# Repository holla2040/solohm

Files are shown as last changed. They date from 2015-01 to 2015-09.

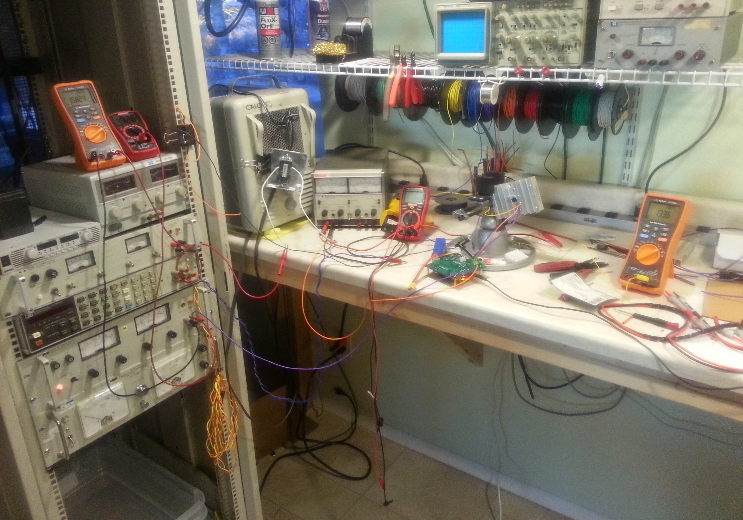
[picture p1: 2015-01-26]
electronicLoadCC3200/board/testing/150125-171110 - Setup.jpg

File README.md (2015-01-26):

solohm
======

Open Source Solar Panel Electronic Load

This project is a hardware/firmware design to aid in testing of solar panels. solohm is powered from the panel's output and an off-the-shelf lipo battery, it can load the panel at its maximum power point, WiFi UDP broadcast current and voltage readings packets, perform IV curve sweeps and measure many temperatures at different panel locations. 

SolOhm replaces bulky expensive, AC-powered, non-waterproof, non-high-temperature rated, multi-unit, wired-communication test equipment with a single unit that's inexpensive, panel-powered, waterproof, industrial temperature rated, and wireless. The goal is 5 minute install: bolt SolOhm to your frame, connect your panel's + and - connectors, attach temperature probes and start testing.  

Specifications
<ul>
<li>Input voltage - 50VDC maximum</li>
<li>Input current - 10A maximum, fused</li>
<li>Input power - 300W maximum</li>
<li>Operating temperature - &lt; 130F, acquisition electronics TEC cooled</li>
<li>Display - OLED graphic display</li>
<li>User interface - IR remote DirectTV RC65X or Sony TV</li> 
<li>MPPT tracking - periodic sweep, perturb/observe, manual</li>
<li>Mechanical - frame/poll attachment, IP63, extruded aluminium, glass/plexiglass, passive heatsink</li>
<li>IV sweep time - &lt; 1 sec, VOC to ISC, 500 samples, Vpanel@ISC < 0.25V@8A<li>
<li>ADC resolution - 12 bit, 4096 steps full scale</li>
<li>Temperature probes - DS18B20, COTS stainless steel, multi-drop, +/-0.5C over -10C to +85C</li>
<li>Power supply - COTS 3S LIPO battery, panel powered charger, 24 hour operation</li>
<li>Data transmission - UDP broadcast and control, HTTP REST</li>
<li>Data collection - micro SD slot</li>
<li>Timestamp - UTC via NTP source with battery-backed real time clock</li>
<li>Firmware - OTA updates (planned)</li>
<li>Calibration - Requires 40V@10A power supply, precision voltmeter and ammeter</li>

</ul>

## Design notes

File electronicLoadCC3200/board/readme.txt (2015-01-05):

This information, board files, assembly instructions and bill of
materials is company confidental.
Not for distribution.

board
    solohm

version
    0.1
    150101

description
    Top layer:                  pcbname.GTL
    Bottom layer:               pcbname.GBL
    Solder Stop Mask top:       pcbname.GTS
    Solder Stop Mask Bottom:    pcbname.GBS
    Silk Top:                   pcbname.GTO
    Silk Bottom:                pcbname.GBO
    NC Drill:                   pcbname.TXT

    drd drill data
    dri drill info
    gpi gerber info

fudicials at
    0.25,0.1
    3.6,3.8

layer stack up sequence
    top     x.GTL
    bottom  x.GBL

contact info
    Craig Hollabaugh
    970 690 4911
    craig@hollabaugh.com

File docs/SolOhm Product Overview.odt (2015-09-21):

SolOhm

Lowering Panel Testing Costs

Montrose, Colorado

Craig Hollabaugh

holla@solohm.com

970 316 3165

https://github.com/holla2040/solohm

SolOhm - Monitor

Lowering Panel Testing Costs

SolOhm - Monitor

Ammeter, 10A range, 1.2mOhm sense resistor

Voltmeter, 50VDC range

Temperature Sensors, multiple, daisy-chained, digital +/- 0.5C -10 to +85C, DS18B20

Wireless Status Broadcast, WiFi

Calibration, requires external power supply, ammeter and voltmeter

Panel Powered

Plastic Enclosure, 3”x3”x2”, IP54

String inverter or micro-inverter operation

HTTP REST and UDP broadcast communications

Open Source hardware and software

Over the air firmware update

Arduino development environment, experienced firmware developer not required

SolOhm - Sweep

Lowering Panel Testing Costs

SolOhm - Sweep

Ammeter, 10A range, 1.2mOhm sense resistor

Voltmeter, 50VDC range

Temperature Sensors, multiple, daisy-chained, digital +/- 0.5C -10 to +85C, DS18B20

Wireless Status Broadcast, WiFi

Calibration, requires external power supply, ammeter and voltmeter

Panel Powered

Plastic Enclosure, 3”x3”x3”, IP54

String inverter or micro-inverter operation

HTTP REST and UDP broadcast communications

Open Source hardware and software

Over the air firmware update

Arduino development environment, experienced firmware developer not required

IV Curve Sweep, 300W range, less than 1 second acquisition time

Internal string disconnect circuit

24-hour operation using LiPo battery

SolOhm - Load

Lowering Panel Testing Costs

SolOhm - Load

Ammeter, 10A range, 1.2mOhm sense resistor

Voltmeter, 50VDC range

Temperature Sensors, multiple, daisy-chained, digital +/- 0.5C -10 to +85C, DS18B20

Wireless Status Broadcast, WiFi

Calibration, requires external power supply, ammeter and voltmeter

Panel Powered

Enclosure, 8”x8”x5”, IP54

String inverter or micro-inverter operation

HTTP REST and UDP broadcast communications

Open Source hardware and software

Over the air firmware update

Arduino development environment, experienced firmware developer not required

IV Curve Sweep, 300W range, less than 1 second acquisition time

Internal string disconnect circuit

24-hour operation using LiPo battery

MPPT

Fan-cooled heat sink

TEC cooled analog circuitry

MPPT, CV, CC modes

Real time clock for timestamp generation

uSD card for disconnected data logging

OLED Display

GSM/GPRS option

SolOhm - µInverter

Lowering Panel Testing Costs

SolOhm - µInverter

Ammeter, 10A range, 1.2mOhm sense resistor

Voltmeter, 50VDC range

Temperature Sensors, multiple, daisy-chained, digital +/- 0.5C -10 to +85C, DS18B20

Wireless Status Broadcast, WiFi

Calibration, requires external power supply, ammeter and voltmeter

Panel Powered

Enclosure, 8”x8”x5”, IP54

HTTP REST and UDP broadcast communications

Open Source hardware and software

Over the air firmware update

Arduino development environment, experienced firmware developer not required

IV Curve Sweep, 300W range, less than 1 second acquisition time

24-hour operation using LiPo battery

MPPT

Fan-cooled heat sink

TEC cooled analog circuitry

MPPT, CV, CC modes

Real time clock for timestamp generation

uSD card for disconnected data logging

OLED Display

GSM/GPRS option

Grid tie

High-precision multiple PWM/ADC control loops

Precision AC measurements, line frequency, voltage, current

On-board DSP

SolOhm Product Overview - 150205

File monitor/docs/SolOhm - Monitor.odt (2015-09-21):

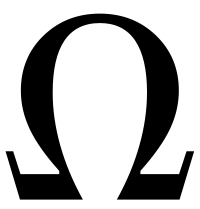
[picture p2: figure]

SolOhm – Monitor 7/1/2015

High-Precision Panel/String Monitor

Feature Set

Use Cases Supported | ● Single panel power verification with temperatures ● Microinverter MPPT verification and sweep capture ● String power verification with temperatures ● String inverter MPPT verification and sweep capture ● Electronic load sweep capture
Tri-range Voltmeter LTC2348-18 | Full scale Resolution 60VDC < 1mV 120VDC < 2mV 700VDC < 10mV
Ammeter LTC2348-18 | 10A < 0.2mA
Temperature Sensor Inputs LTC2983 | 5 RTD – 2,3,4 wire 10 Thermocouples - B, E, J, K, N, S, R, T 0.1°C accuracy and 0.001°C resolution
Operating Temperature Range | -20°C to 60°C, holds measurement accuracy over range
Real Time Clock | NTP time reference synchronization Disconnected accuracy < 0.3sec/day
Power Supply Turnigy Lipo | Rechargeable/replaceable COTS 3-cell LiPo battery Parasitically panel powered, < 0.01% consumption Consumption disabled during data acquisition
Sampling | Simultaneous voltage and current measurement No multi-channel multiplexer 18-bit, 200K samples/sec max, full differential Configurable sample rate between 1/5min – 200K/sec
Data Storage uSDHC | 4GB non-removable – FAT32 file system, timestamped data, date-based filenames, CSV format
Configuration | Bluetooth enabled cell phone application (IOS/Android) Settings: user label, sample rate, data transfer frequency/destination URL, filename format, WiFi configuration, timezone, calibration constants
Communication | Bluetooth Low Energy configuration and data display, phone app will show live summary table of all field devices, WiFi data transfer
Calibration | Requires power supply and precision voltmeter/ammeter
Enclosure | 3”x5”x3”, plastic, IP65, MC4 pigtail connections, mountable, no high voltage access, no buttons, no display, safety markings, viewable serial number
Price | $990.00

SolOhm Monitor v1.0 ● SolOhm ● Montrose, CO, USA ● 970 316 3165 ● www.solohm.com

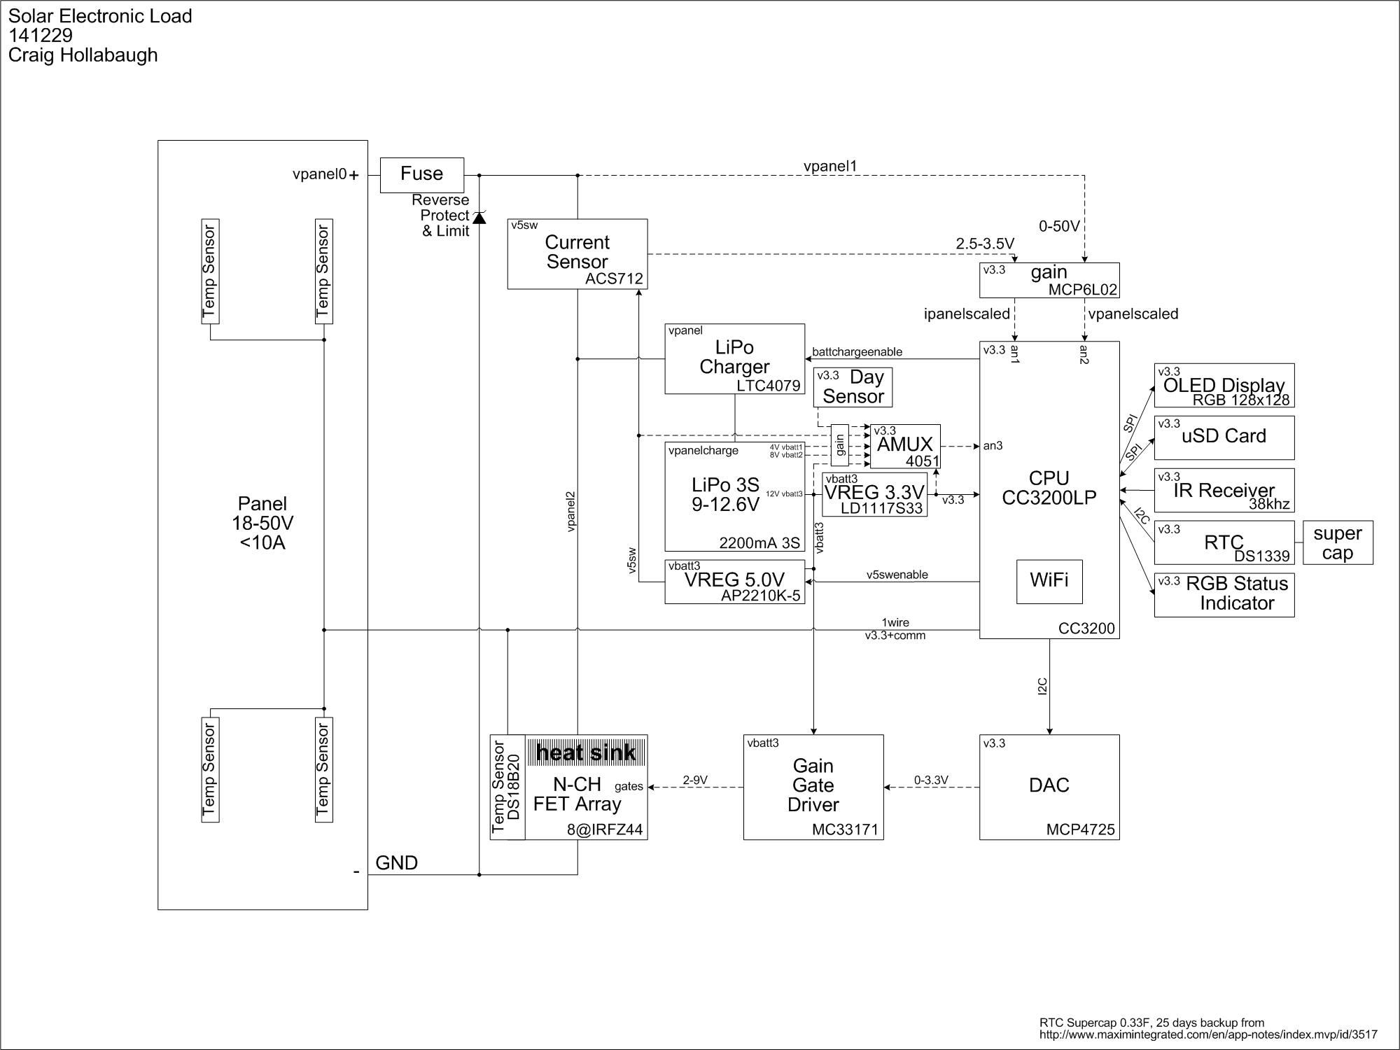
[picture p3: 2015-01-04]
electronicLoadCC3200/design/Solar Electronic Load LiPo Architecture.jpg

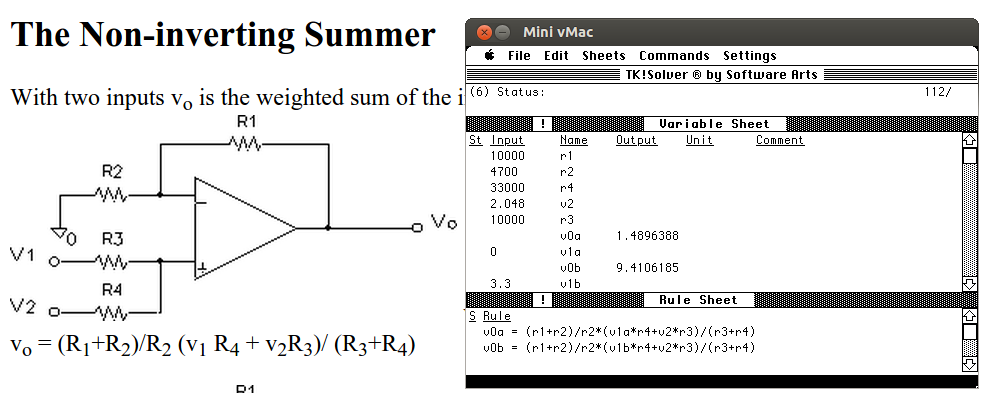
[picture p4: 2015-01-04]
electronicLoadCC3200/design/gate driver biasing.png

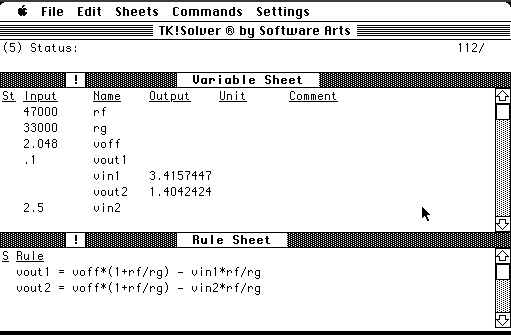
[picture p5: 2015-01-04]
electronicLoadCC3200/design/current gain with offset.png

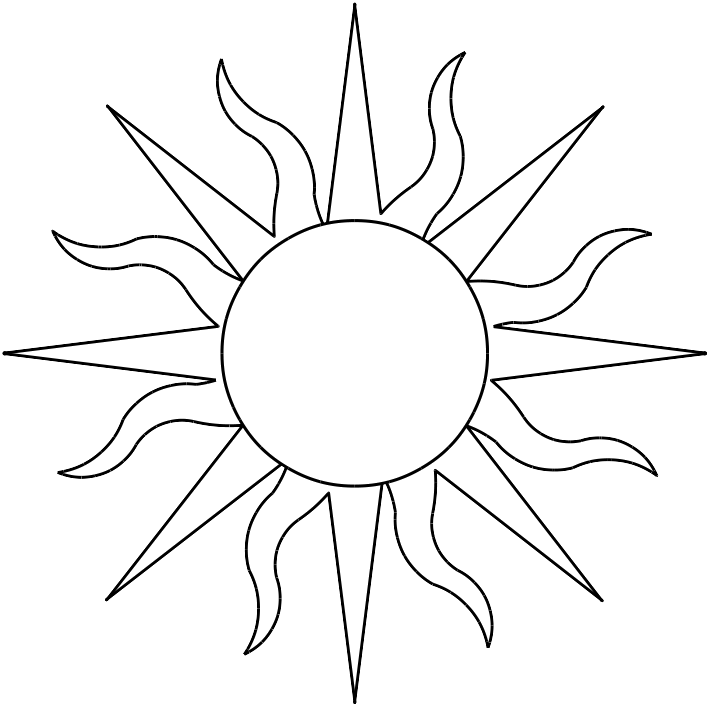
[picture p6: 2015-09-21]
docs/sol.png

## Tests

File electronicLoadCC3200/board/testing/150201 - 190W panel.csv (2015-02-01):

dac | voltage | current | rload | power
1000 | 40.40 | 0.04 | 935.04 | 1.74
1004 | 40.37 | 0.05 | 757.05 | 2.15
1008 | 40.39 | 0.04 | 992.93 | 1.64
1012 | 40.35 | 0.04 | 933.91 | 1.74
1016 | 40.36 | 0.04 | 836.20 | 1.94
1020 | 40.37 | 0.05 | 757.05 | 2.15
1024 | 40.31 | 0.04 | 881.42 | 1.84
1028 | 40.32 | 0.04 | 881.68 | 1.84
1032 | 40.42 | 0.04 | 993.83 | 1.64
1036 | 40.40 | 0.04 | 883.29 | 1.84
1040 | 40.36 | 0.04 | 836.20 | 1.94
1044 | 40.39 | 0.05 | 757.28 | 2.15
1048 | 40.39 | 0.05 | 757.28 | 2.15
1052 | 40.37 | 0.04 | 992.63 | 1.64
1056 | 40.39 | 0.05 | 795.02 | 2.05
1060 | 40.37 | 0.04 | 882.75 | 1.84
1064 | 40.39 | 0.04 | 992.93 | 1.64
1068 | 40.37 | 0.04 | 882.75 | 1.84
1072 | 40.39 | 0.04 | 883.02 | 1.84
1076 | 40.34 | 0.04 | 991.73 | 1.64
1080 | 40.36 | 0.04 | 882.49 | 1.84
1084 | 40.41 | 0.03 | 1059.47 | 1.54
1088 | 40.39 | 0.04 | 934.75 | 1.74
1092 | 40.40 | 0.04 | 883.29 | 1.84
1096 | 40.36 | 0.05 | 756.82 | 2.15
1100 | 40.37 | 0.04 | 882.75 | 1.84
1104 | 40.39 | 0.04 | 992.93 | 1.64
1108 | 40.40 | 0.04 | 993.23 | 1.64
1112 | 40.36 | 0.04 | 934.19 | 1.74
1116 | 40.39 | 0.04 | 883.02 | 1.84
1120 | 40.39 | 0.04 | 934.75 | 1.74
1124 | 40.39 | 0.04 | 934.75 | 1.74
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

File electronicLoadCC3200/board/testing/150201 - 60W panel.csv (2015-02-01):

dac | voltage | current | rload | power
1000 | 20.50 | 0.06 | 299.17 | 1.40
1002 | 20.52 | 0.06 | 323.42 | 1.30
1004 | 20.50 | 0.05 | 366.95 | 1.14
1006 | 20.50 | 0.07 | 278.58 | 1.50
1008 | 20.53 | 0.06 | 311.20 | 1.35
1010 | 20.50 | 0.06 | 310.64 | 1.35
1012 | 20.52 | 0.05 | 404.00 | 1.04
1014 | 20.56 | 0.05 | 368.05 | 1.14
1016 | 20.51 | 0.06 | 310.83 | 1.35
1018 | 20.51 | 0.05 | 351.25 | 1.19
1020 | 20.53 | 0.05 | 385.06 | 1.09
1022 | 20.53 | 0.07 | 289.03 | 1.45
1024 | 20.52 | 0.05 | 351.46 | 1.19
1026 | 20.55 | 0.05 | 351.88 | 1.20
1028 | 20.52 | 0.06 | 323.42 | 1.30
1030 | 20.50 | 0.06 | 336.46 | 1.24
1032 | 20.51 | 0.06 | 336.66 | 1.24
1034 | 20.53 | 0.06 | 323.61 | 1.30
1036 | 20.53 | 0.06 | 337.06 | 1.25
1038 | 20.53 | 0.06 | 337.06 | 1.25
1040 | 20.53 | 0.05 | 351.67 | 1.19
1042 | 20.55 | 0.05 | 367.83 | 1.14
1044 | 20.53 | 0.06 | 337.06 | 1.25
1046 | 20.51 | 0.05 | 384.60 | 1.09
1048 | 20.51 | 0.05 | 351.25 | 1.19
1050 | 20.52 | 0.06 | 336.86 | 1.25
1052 | 20.51 | 0.05 | 351.25 | 1.19
1054 | 20.52 | 0.05 | 384.83 | 1.09
1056 | 20.53 | 0.06 | 337.06 | 1.25
1058 | 20.55 | 0.05 | 385.29 | 1.09
1060 | 20.55 | 0.06 | 323.81 | 1.30
1062 | 20.52 | 0.06 | 336.86 | 1.25
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

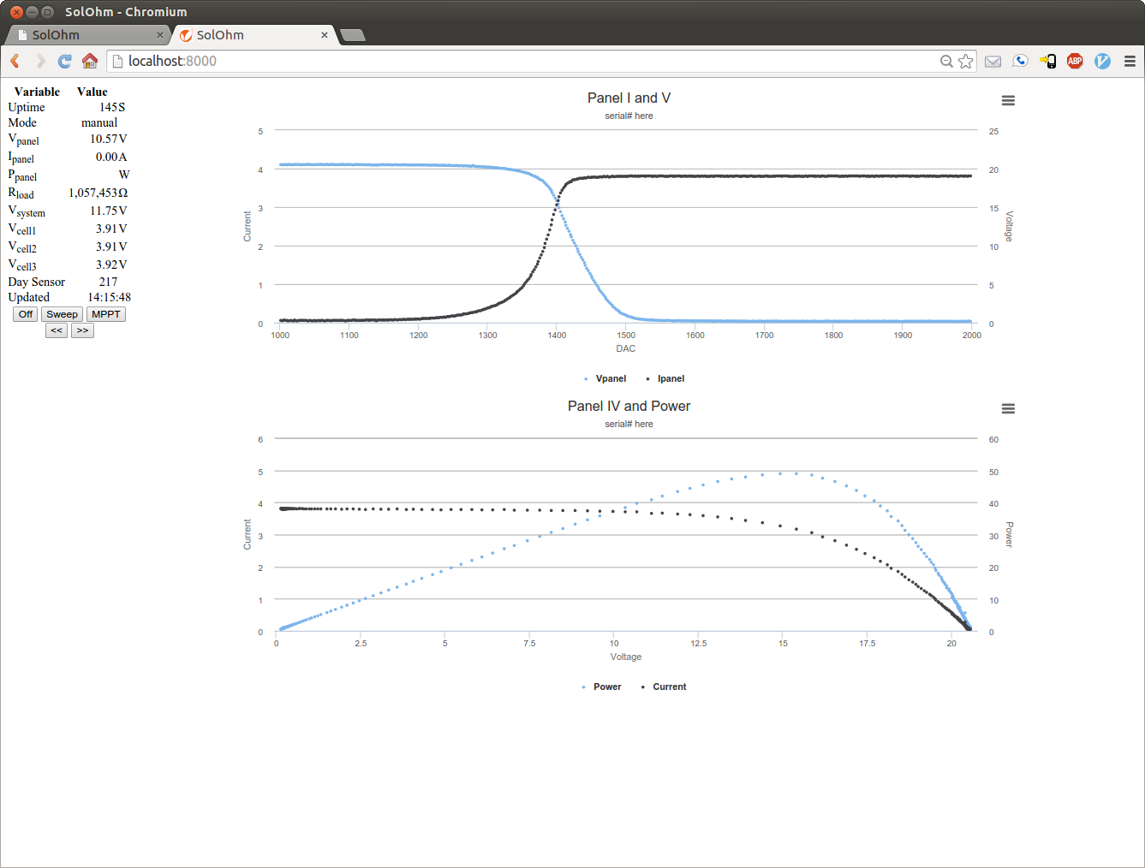
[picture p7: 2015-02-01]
electronicLoadCC3200/board/testing/150201 - 60W panel SolOhm Dashboard.png

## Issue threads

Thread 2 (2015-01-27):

D1 has wrong footprint

holla2040, 2015-01-27:

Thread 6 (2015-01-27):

LED indicators

holla2040, 2015-01-27:
consider ditching activity LED if LP LED is sufficient
    make it RED to match or not drill led holes

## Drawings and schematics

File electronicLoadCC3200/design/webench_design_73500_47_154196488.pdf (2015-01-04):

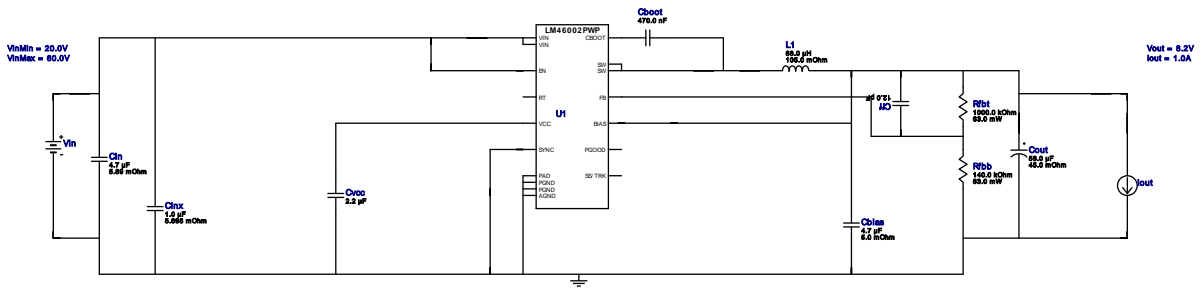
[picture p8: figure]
Cboot 470.0 nF; Cin 4.7 µF 5.89 mOhm; Cinx 1.0 µF 5.698 mOhm; Cout 56.0 µF; 45.0 mOhm; Cvcc 2.2 µF; L1 68.0 µH 105.0 mOhm; Rfbb 140.0 kOhm 63.0 mW; Rfbt 1000.0 kOhm; LM46002PWP; CBOOT; BIAS; SYNC; VIN VIN; VCC; PGOOD; SS/ TRK; AGND; PGND; PAD; VinMin = 20.0V VinMax = 60.0V; Vout = 8.2V Iout = 1.0A; Cbias 4.7 µF 5.0 mOhm; Vin; Iout

Copyright © 2014, Texas Instruments Incorporated | 1 | ti.com/webench

WEBENCH®
Design Report LM46002PWPR : solarelectronicload-lipo December 22, 2014 11:17:29 GMT-08:00

## WEBENCH ® Design Report

Design : 73500/47 LM46002PWPR
solarelectronicload-lipo

VinMin = 20.0V
VinMax = 60.0V
Vout = 8.2V
Iout = 1.0A

Device = LM46002PWPR
Topology = Buck
Created = 12/22/14 11:13:52 AM BOM Cost = $3.80
Footprint = 420.0 mm²
BOM Count = 11
Total Pd = 0.89W
1. The input capacitor included in the BOM only contains a small filter capacitor that should be placed near the IC. Depending on where the power supply is laid out in the system additional bulk capacitance may need to be added to filter the line ripple.
2. If there is no VinTyp specified, WEBENCH will use the VinMax value. To change the VinTyp value, click on the "Change Design Inputs" button under the Optimization Tuning knob. In some applications, while the design requires the input voltage to be a wide range, for a majority of the time, it is operating at a much lower voltage than the maximum input voltage. Sizing the inductor based on the maximum input voltage may yield an inductance much larger than typically needed, causing a larger footprint for the overall design. At the same time, components such as the input capacitor must be rated based on the maximum input voltage. WEBENCH now supports the use of this additional input voltage specification.

## Electrical BOM

# Name | Manufacturer | Part Number | Properties | Qty Price | Footprint

1. Cbias | MuRata | GRM21BR61C475KA88L (http://search.murata.co.jp/Ceramy/PnsearchViewAction.do) Series= X5R | Cap= 4.7 uF ESR= 5.0 mOhm VDC= 16.0 V IRMS= 0.0 A
1 | $0.04
| | | | | 0805 7 mm²
2. Cboot | MuRata | GRM21BR72A474KA73L (http://search.murata.co.jp/Ceramy/PnsearchViewAction.do) Series= X7R

Cap= 470.0 nF
VDC= 100.0 V
IRMS= 0.0 A

1 $0.13
0805 7 mm²
3. Cff | AVX | 06033A120FAT2A (http://www.avx.com/docs/Catalogs/ccog.pdf) Series= C0G/NP0

Cap= 12.0 pF
VDC= 25.0 V
IRMS= 0.0 A

1 $0.10
0603 5 mm²
4. Cin | TDK | C3225X7S2A475M200AB (http://product.tdk.com/capacitor/mlcc/en/documents/mlcc%5Fcommercial%5Fmidvoltage%5Fen.pdf) Series= X7R

Cap= 4.7 uF
ESR= 5.89 mOhm
VDC= 100.0 V
IRMS= 6.7739 A

1 $0.42

1210 15 mm²

5. Cinx | TDK | C3216JB2A105K (http://www.tdk.co.jp/tefe02/e3941%5Fc.pdf) Series= 285

Cap= 1.0 uF
ESR= 5.698 mOhm
VDC= 100.0 V
IRMS= 0.0 A

1 $0.11
1206 11 mm²
6. Cout | Panasonic | 16SVP56M (http://www.edc.sanyo.com/english/pdf/oscon/E32.pdf) Series= 261

Cap= 56.0 uF
ESR= 45.0 mOhm
VDC= 16.0 V
IRMS= 1.89 A

1 $0.49

SM_RADIAL_8MM 113 mm²
7. Cvcc | Kemet | C0603C225K9PACTU (http://www.kemet.com/kemet/web/homepage/kechome.nsf/vapubfiles/F3102%5FY5V.pdf/%24file/F3102%5FY5V.pdf) Series= X5R | Cap= 2.2 uF VDC= 6.3 V IRMS= 0.0 A
1 | $0.02
0603 5 mm²
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

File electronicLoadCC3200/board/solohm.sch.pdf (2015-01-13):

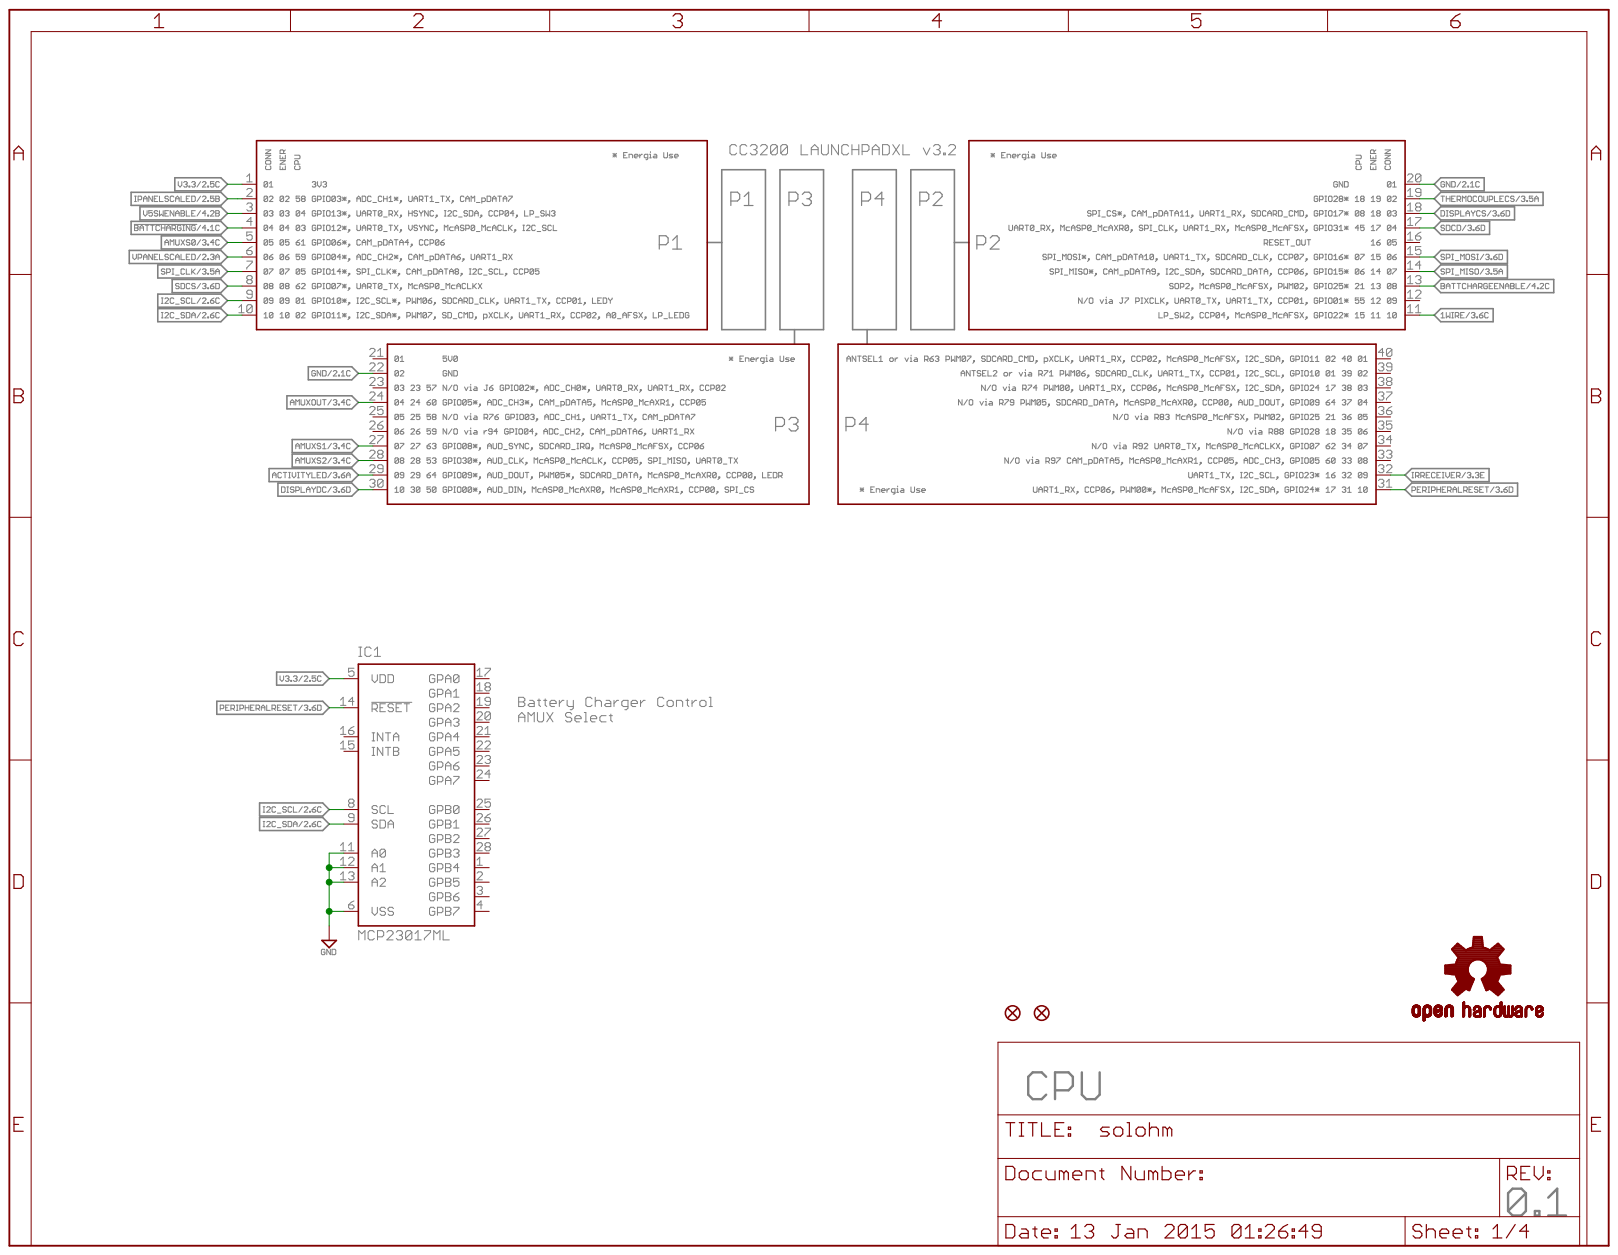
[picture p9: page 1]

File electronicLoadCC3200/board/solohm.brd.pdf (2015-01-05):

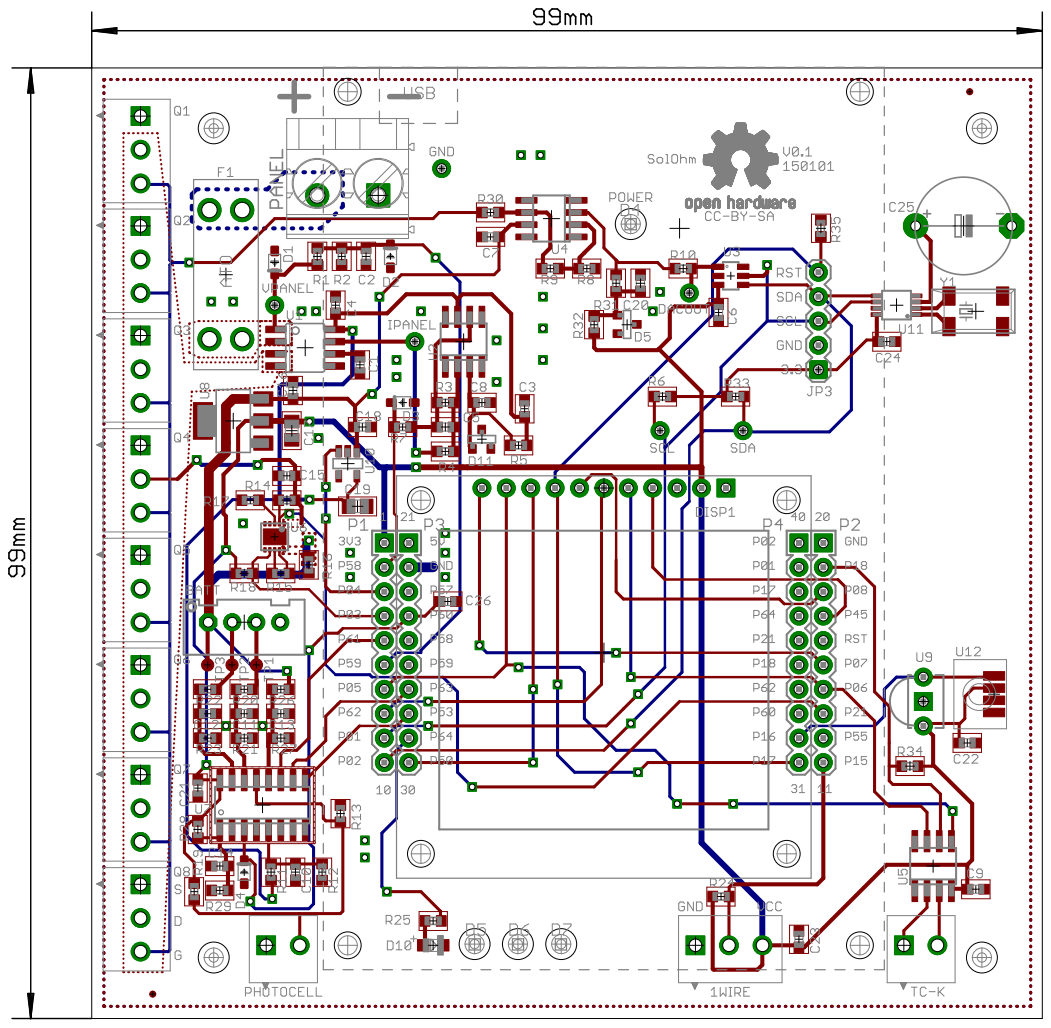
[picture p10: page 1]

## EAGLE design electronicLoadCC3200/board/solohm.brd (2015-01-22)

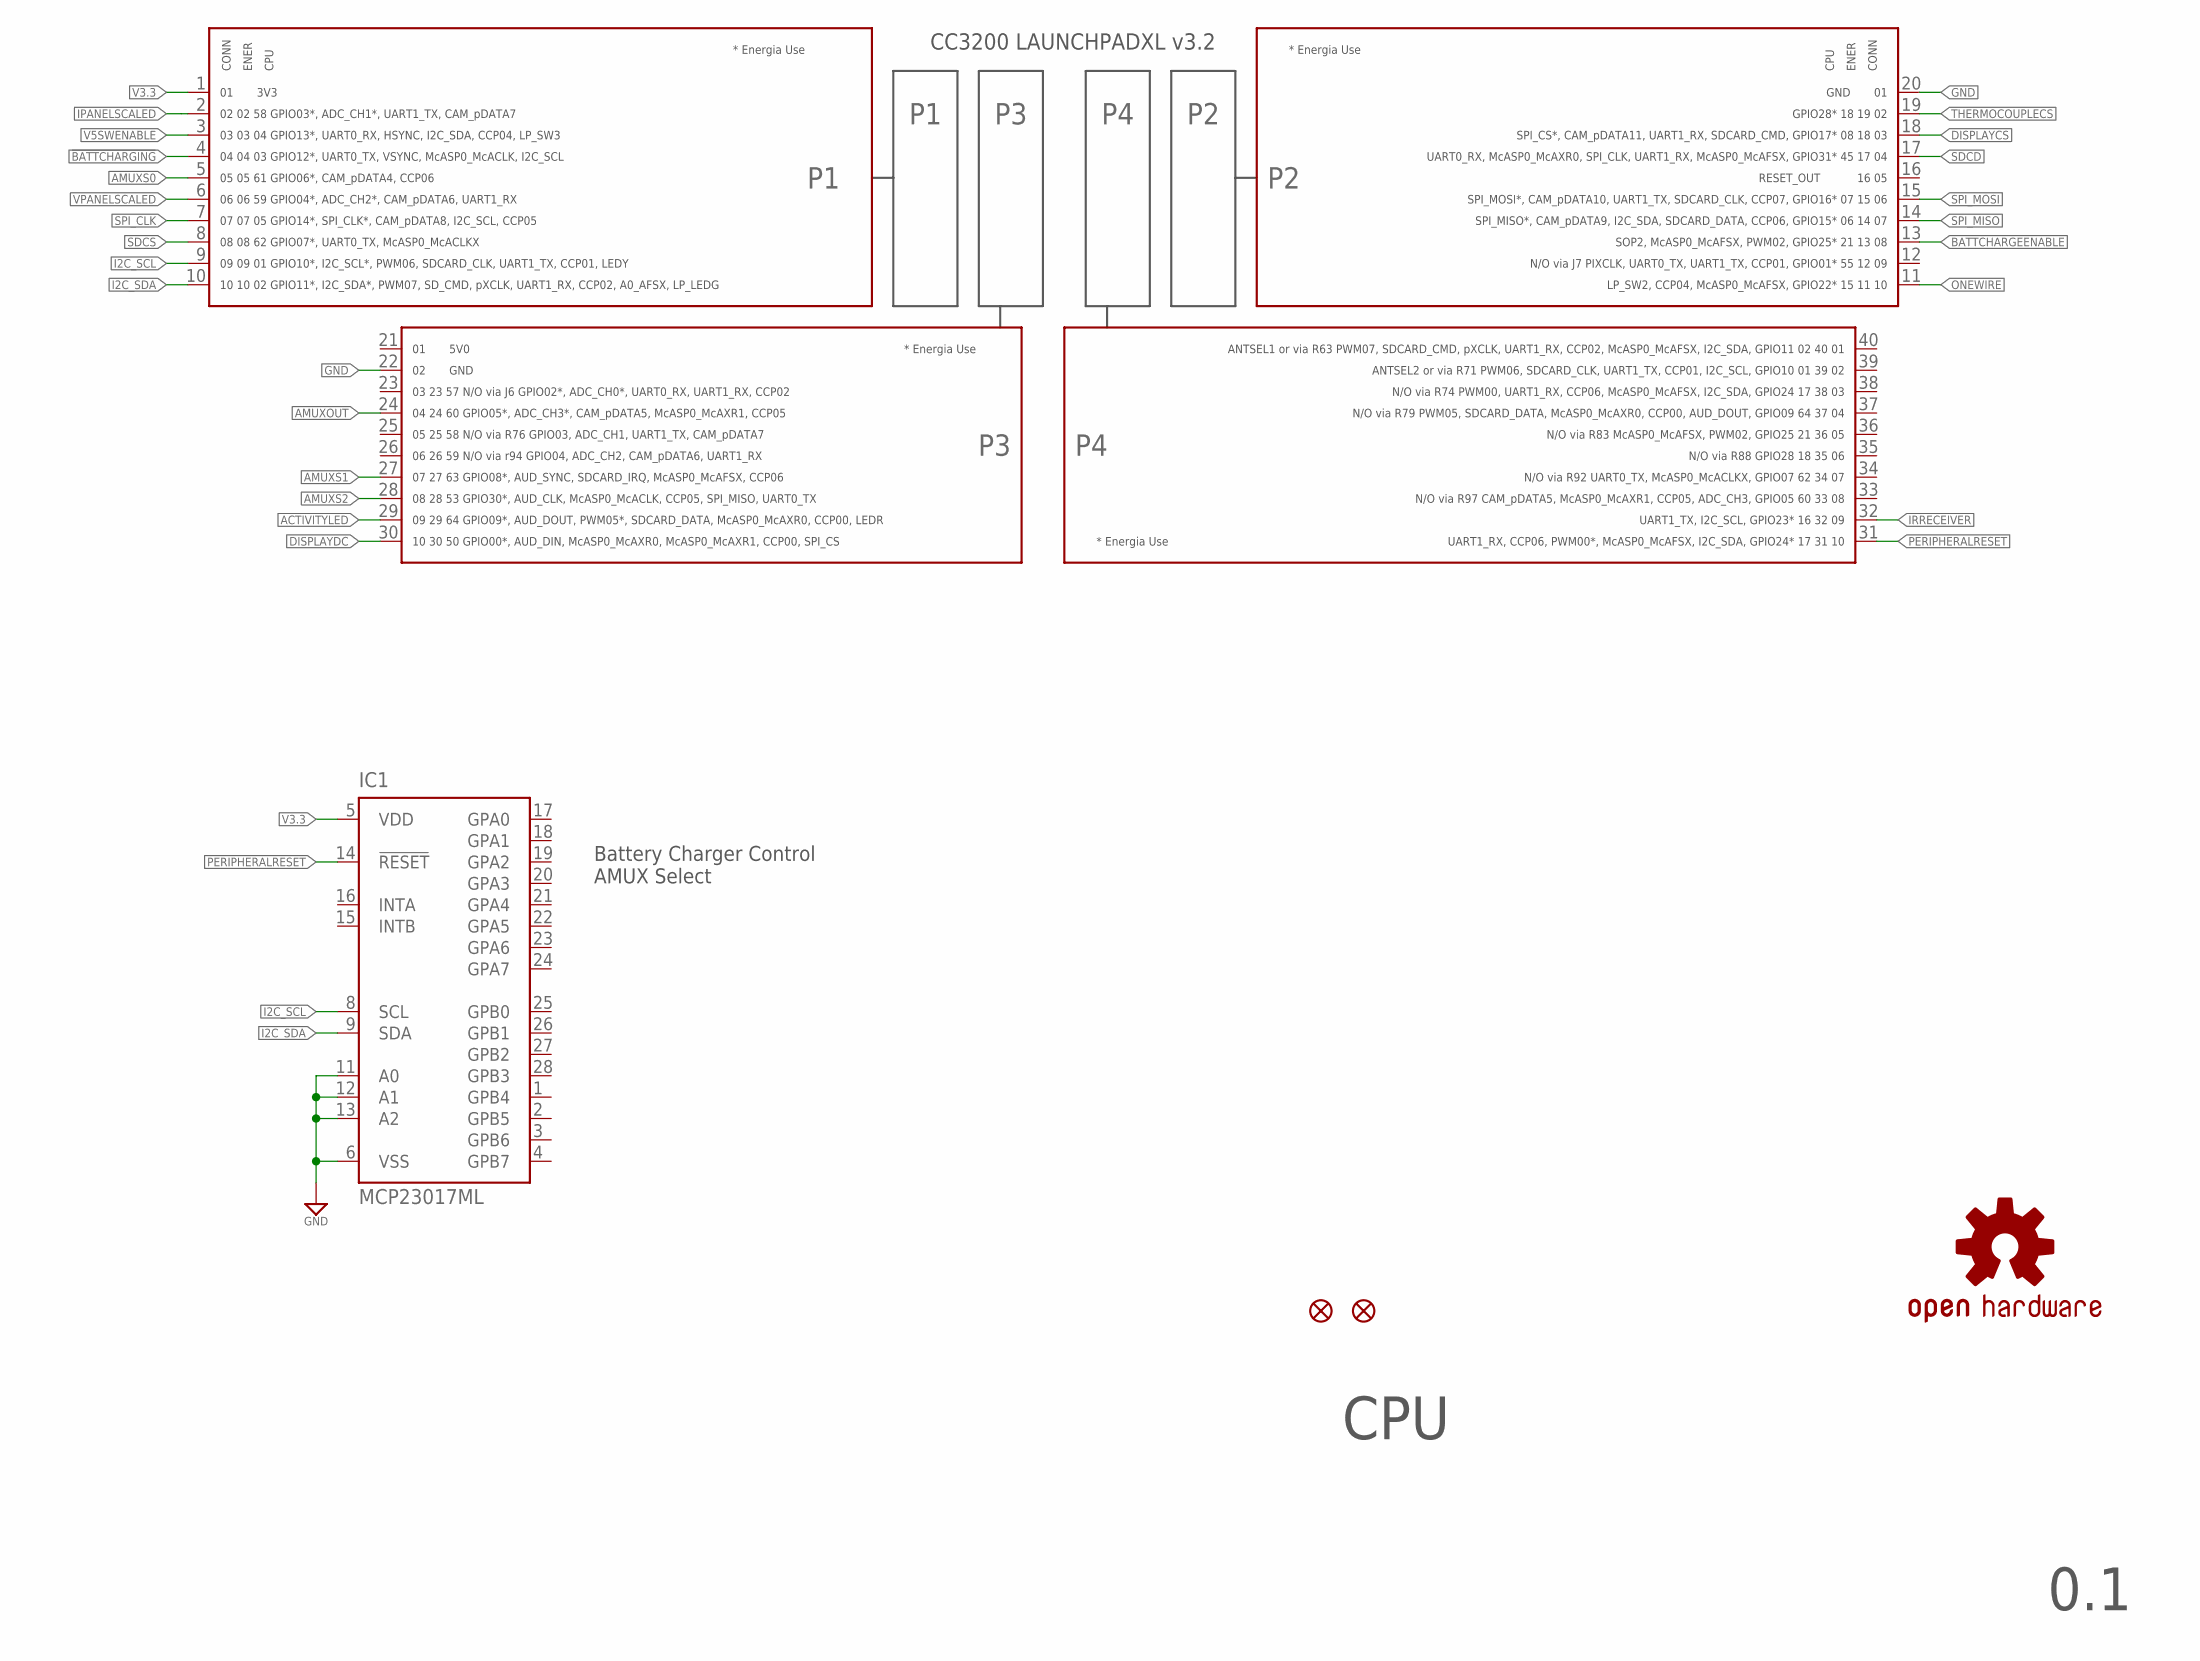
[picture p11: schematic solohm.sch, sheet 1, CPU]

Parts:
A1: CC3200-LAUNCHXL-BOOSTERPACK
IC1: MCP23017ML; QFN28-ML_6X6MM
JP1, JP2: FIDUCIALUFIDUCIAL; MICRO-FIDUCIAL
LOGO1: LOGO-OSHWL; LOGO-OSHW-L

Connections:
!BATTCHARGING: A1.4; also elsewhere on the board
ACTIVITYLED: A1.29; also elsewhere on the board
AMUXOUT: A1.24; also elsewhere on the board
AMUXS0: A1.5; also elsewhere on the board
AMUXS1: A1.27; also elsewhere on the board
AMUXS2: A1.28; also elsewhere on the board
BATTCHARGEENABLE: A1.13; also elsewhere on the board
DISPLAYCS: A1.18; also elsewhere on the board
DISPLAYDC: A1.30; also elsewhere on the board
GND: A1.20, A1.22, IC1.6 (VSS), IC1.11 (A0), IC1.12 (A1), IC1.13 (A2); also elsewhere on the board
I2C_SCL: A1.9, IC1.8 (SCL); also elsewhere on the board
I2C_SDA: A1.10, IC1.9 (SDA); also elsewhere on the board
IPANELSCALED: A1.2; also elsewhere on the board
IRRECEIVER: A1.32; also elsewhere on the board
ONEWIRE: A1.11; also elsewhere on the board
PERIPHERALRESET: A1.31, IC1.14 (!RESET); also elsewhere on the board
SDCD: A1.17; also elsewhere on the board
SDCS: A1.8; also elsewhere on the board
SPI_CLK: A1.7; also elsewhere on the board
SPI_MISO: A1.14; also elsewhere on the board
SPI_MOSI: A1.15; also elsewhere on the board
THERMOCOUPLECS: A1.19; also elsewhere on the board
V3.3: A1.1, IC1.5 (VDD); also elsewhere on the board
V5SWENABLE: A1.3; also elsewhere on the board
VPANELSCALED: A1.6; also elsewhere on the board

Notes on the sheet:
CPU
0.1
Battery Charger Control AMUX Select

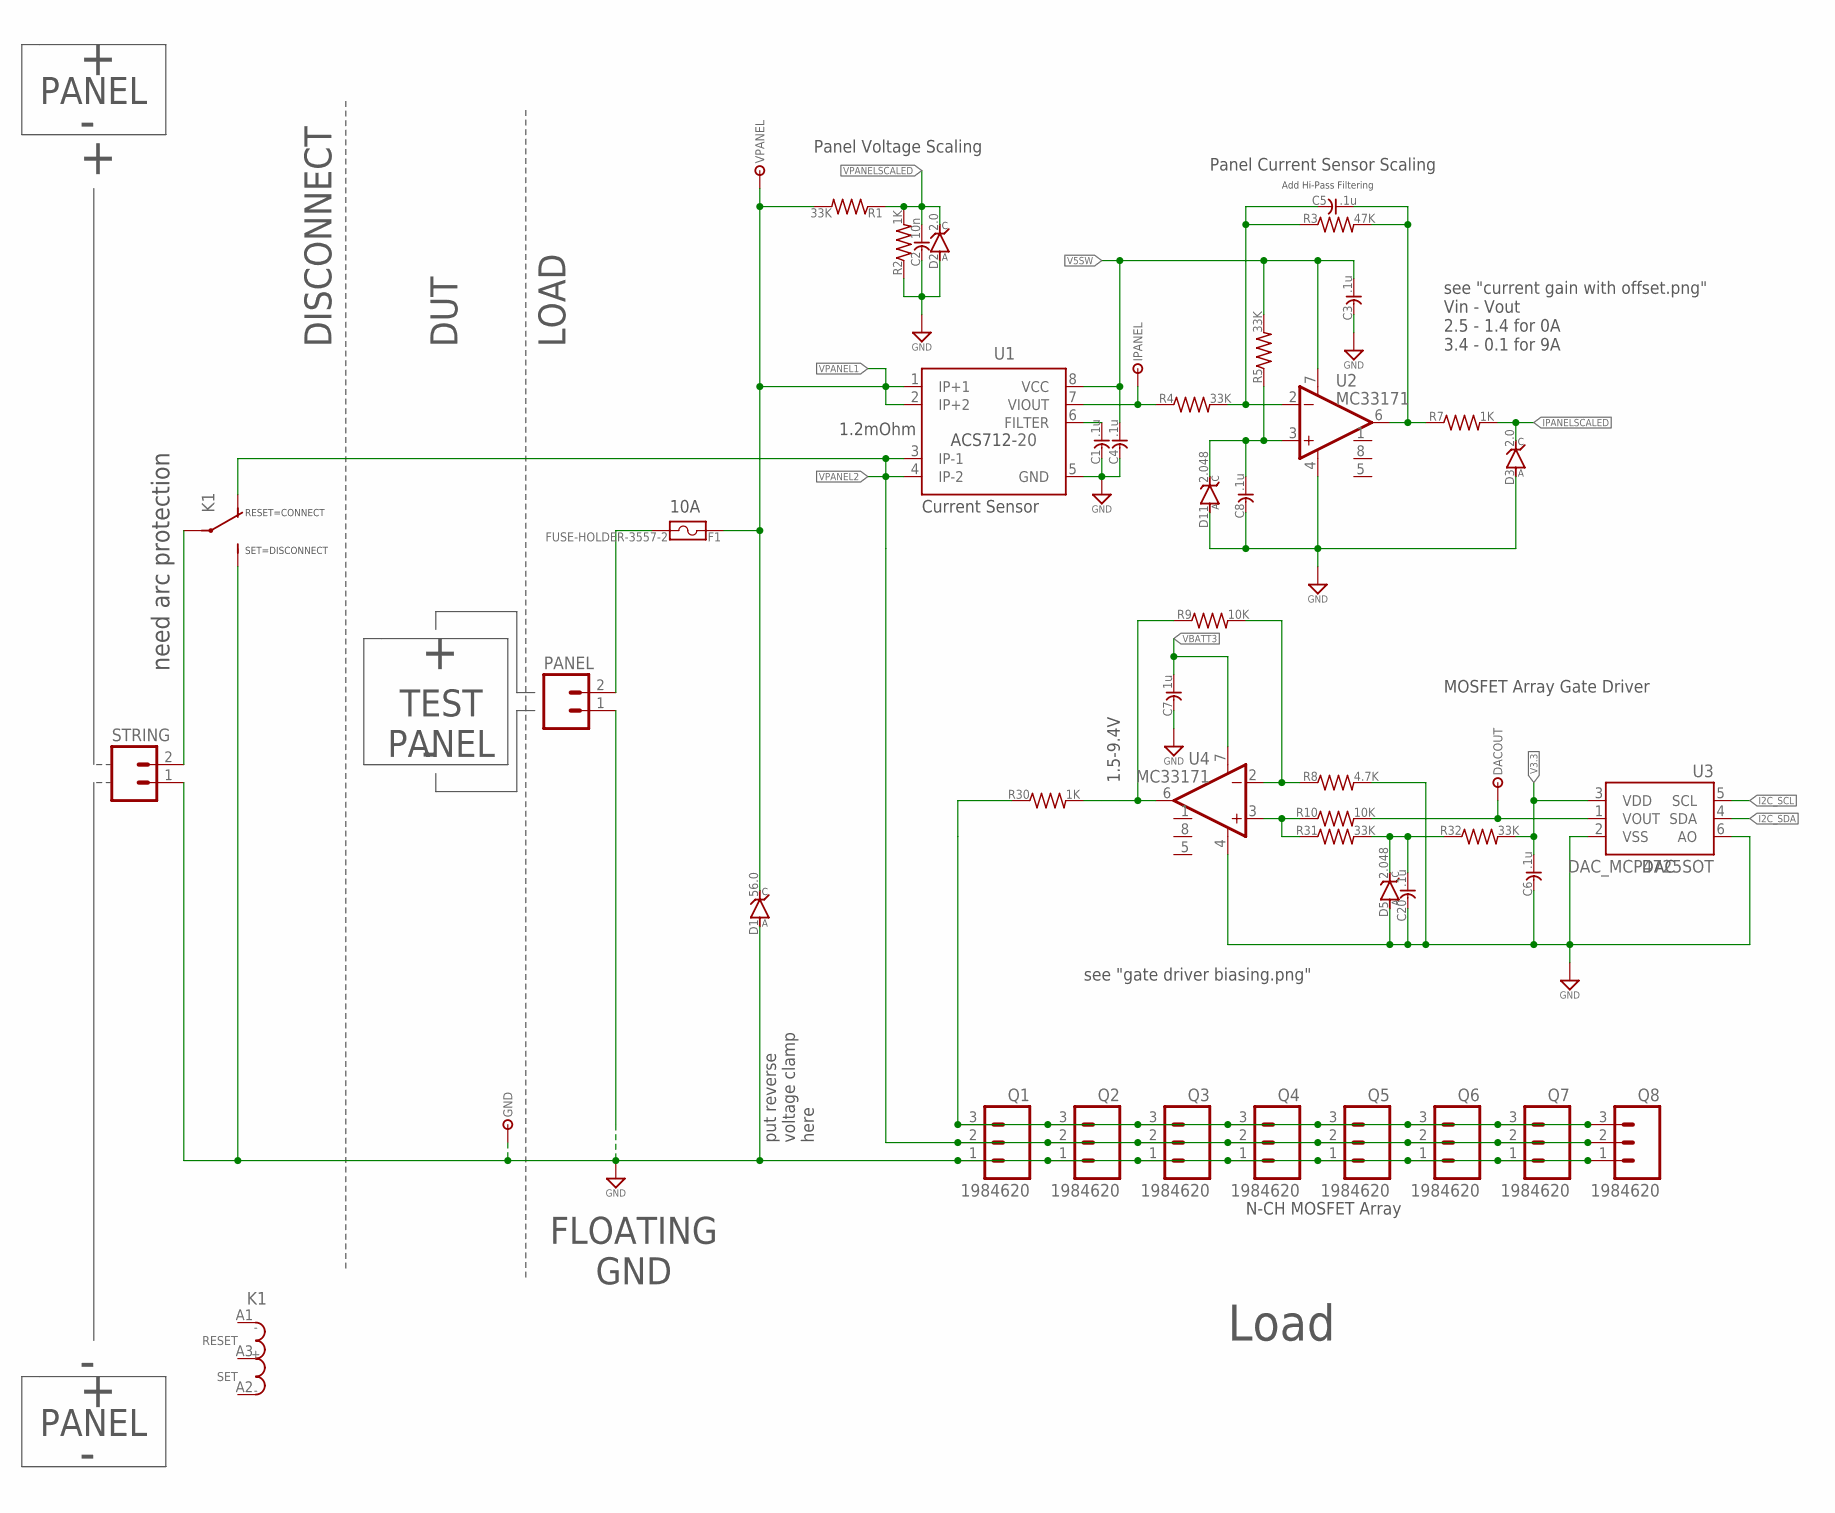
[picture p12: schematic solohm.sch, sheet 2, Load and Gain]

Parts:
C1, C3, C4, C5, C6, C8, C20: .1u; C0603
C2: 10n; C0603
C7: 1u; C0603
D1: 56.0; SOD-323
D2, D3: 2.0; SOD-323
D5, D11: 2.048; SOT23-3
DACOUT: TESTPOINTTHRU; TPTHRU
F1: FUSE-HOLDER-3557-2; 3557-2
GND: TESTPOINTTHRU; TPTHRU
IPANEL: TESTPOINTTHRU; TPTHRU
K1: RELAY-LATCHING-DUAL-1FORMC-5MM-16A; RELAY-1FORMC-5MM-16A
PANEL: M02-6.35MM; OSTT702
Q1, Q2, Q3, Q4, Q5, Q6, Q7, Q8: 1984620
R1, R4, R5, R31, R32: 33K; R0603
R2, R7, R30: 1K; R0603
R3: 47K; R0603
R8: 4.7K; R0603
R9, R10: 10K; R0603
STRING: M02-6.35MM; OSTT702
U1: 20; SOIC08
U2, U4: MC33171; SO08
U3: DAC_MCP4725SOT; SOT23-6
VPANEL: TESTPOINTTHRU; TPTHRU

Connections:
GATES: Q1.3, Q2.3, Q3.3, Q4.3, Q5.3, Q6.3, Q7.3, Q8.3, R30.1
GND: C1.2, C2.2, C3.2, C4.2, C6.2, C7.2, C8.2, C20.2, D1.A, D2.A, D3.A, D5.2 (A), D11.2 (A), GND.1, K1.14@1 (NO), K1.14@2 (NO), PANEL.1, Q1.1, Q2.1, Q3.1, Q4.1, Q5.1, Q6.1, Q7.1, Q8.1, R2.1, R8.2, STRING.1, U1.5 (GND), U2.4 (V-), U3.2 (VSS), U3.6 (AO), U4.4 (V-); also elsewhere on the board
I2C_SCL: U3.5 (SCL); also elsewhere on the board
I2C_SDA: U3.4 (SDA); also elsewhere on the board
IPANELSCALED: D3.C, R7.2; also elsewhere on the board
unnamed: R9.1, R30.2, U4.6 (OUT)
unnamed: C20.1, D5.1 (C), R31.2, R32.1
unnamed: C1.1, U1.6 (FILTER)
unnamed: IPANEL.1, R4.1, U1.7 (VIOUT)
unnamed: C5.2, R3.1, R4.2, U2.2 (IN-)
unnamed: C8.1, D11.1 (C), R5.1, U2.3 (IN+)
unnamed: C5.1, R3.2, R7.1, U2.6 (OUT)
unnamed: DACOUT.1, R10.2, U3.1 (VOUT)
unnamed: R8.1, R9.2, U4.2 (IN-)
unnamed: R10.1, R31.1, U4.3 (IN+)
unnamed: K1.11@1 (W), K1.11@2 (W), STRING.2
V3.3: C6.1, R32.2, U3.3 (VDD); also elsewhere on the board
V5SW: C3.1, C4.1, R5.2, U1.8 (VCC), U2.7 (V+); also elsewhere on the board
VBATT3: C7.1, U4.7 (V+); also elsewhere on the board
VPANEL0: F1.2@1, F1.2@2, PANEL.2
VPANEL1: D1.C, F1.1@1, F1.1@2, R1.2, U1.1 (IP+1), U1.2 (IP+2), VPANEL.1
VPANEL2: K1.12@1 (NC), K1.12@2 (NC), Q1.2, Q2.2, Q3.2, Q4.2, Q5.2, Q6.2, Q7.2, Q8.2, U1.3 (IP-1), U1.4 (IP-2); also elsewhere on the board
VPANELSCALED: C2.1, D2.C, R1.1, R2.2; also elsewhere on the board

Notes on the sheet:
Load
Add Hi-Pass Filtering
see "gate driver biasing.png"
1.5-9.4V
see "current gain with offset.png" Vin - Vout 2.5 - 1.4 for 0A 3.4 - 0.1 for 9A
10A
DAC
PANEL
LOAD
DISCONNECT
TEST PANEL
FLOATING GND
need arc protection
Current Sensor
1.2mOhm
Panel Current Sensor Scaling
MOSFET Array Gate Driver
N-CH MOSFET Array
DUT
Panel Voltage Scaling
put reverse voltage clamp here
SET=DISCONNECT
RESET=CONNECT

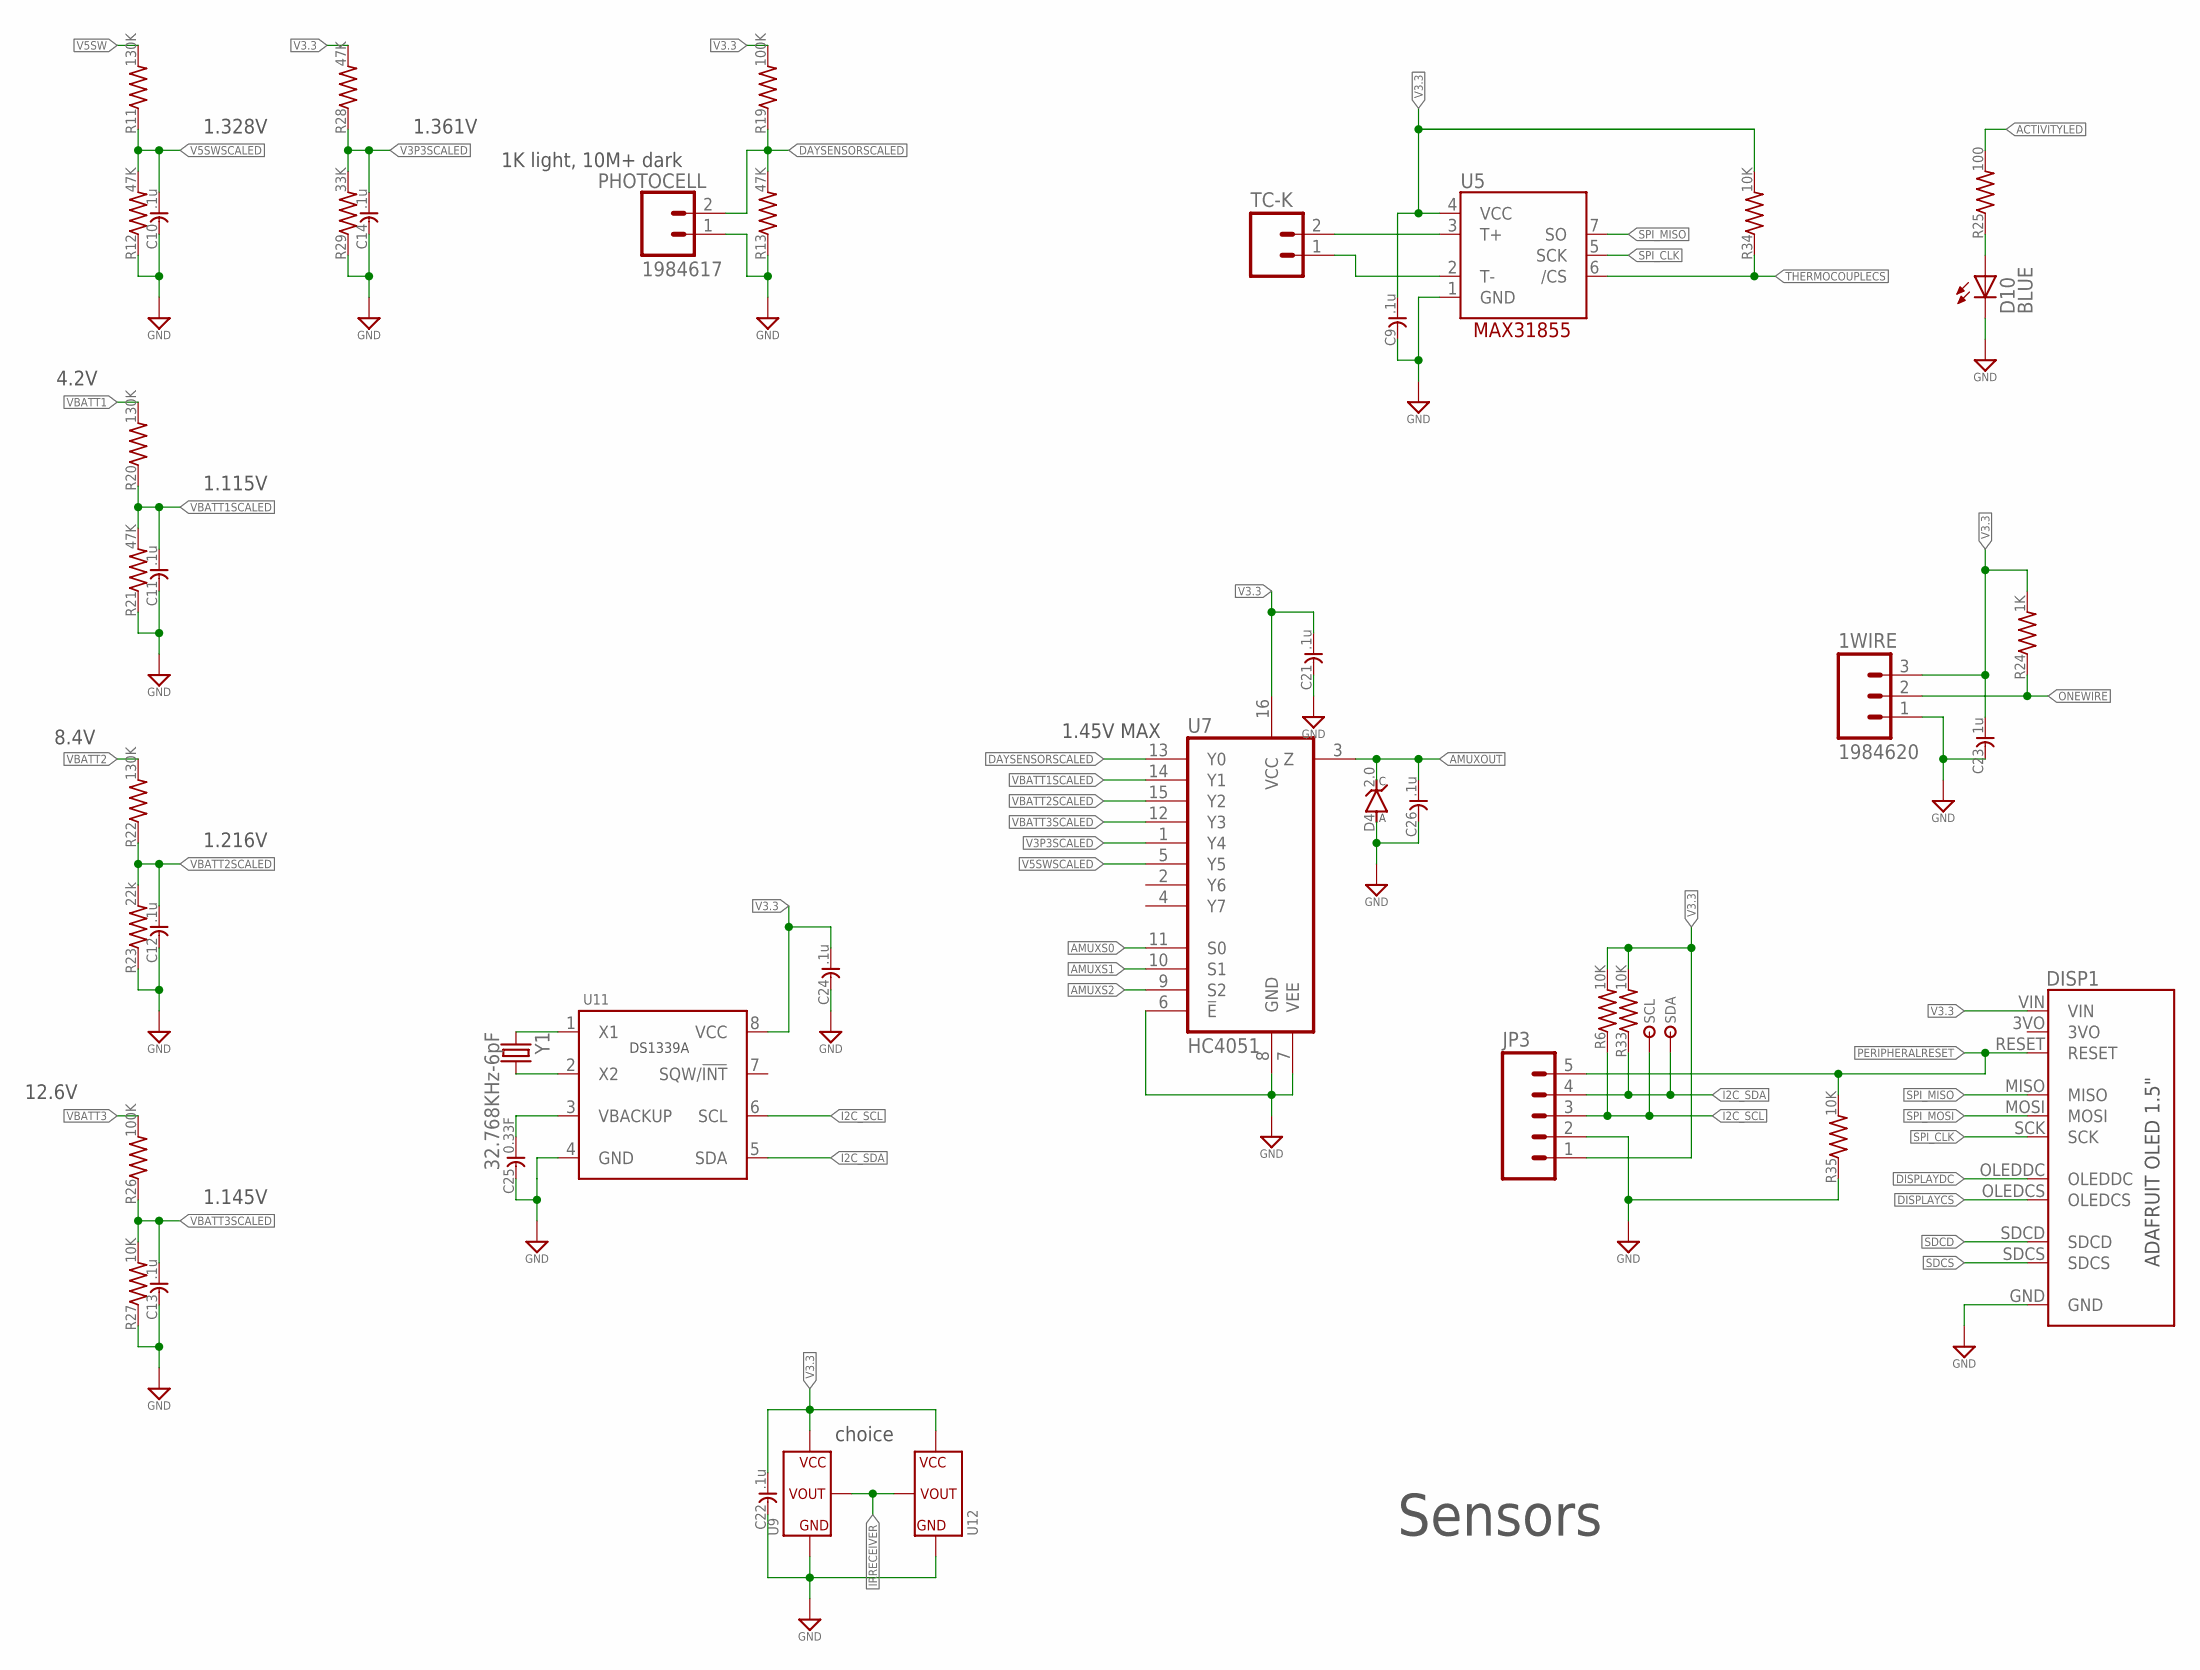
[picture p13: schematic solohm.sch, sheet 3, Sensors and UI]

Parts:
1WIRE: 1984620
C9, C10, C11, C12, C13, C14, C21, C22, C24, C26: .1u; C0603
C23: 1u; C0603
C25: 0.33F; CAP-SUPER-AXIAL-10MM
D4: 2.0; SOD-323
D10: BLUE; LED0805
DISP1: BOARD-DISP-ADAFRUIT-OLED-1.5
JP3: M05PTH; 1X05
PHOTOCELL: 1984617
R6, R27, R33, R34, R35: 10K; R0603
R11, R20, R22: 130K; R0603
R12, R13, R21, R28: 47K; R0603
R19, R26: 100K; R0603
R23: 22k; R0603
R24: 1K; R0603
R25: 100; R0603
R29: 33K; R0603
SCL: TESTPOINTTHRU; TPTHRU
SDA: TESTPOINTTHRU; TPTHRU
TC-K: M02-1984617; 1984617
U5: THERMOCOUPLE-MAX31855; SO08
U7: HC4051; SO16
U9: IRDETECTOR-THRU
U11: RTC-DS1339A; MSOP8
U12: IRDETECTOR-TSOP6X
Y1: 32.768KHz-6pF; ABS25

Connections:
ACTIVITYLED: R25.2; also elsewhere on the board
AMUXOUT: C26.1, D4.C, U7.3 (Z); also elsewhere on the board
AMUXS0: U7.11 (S0); also elsewhere on the board
AMUXS1: U7.10 (S1); also elsewhere on the board
AMUXS2: U7.9 (S2); also elsewhere on the board
DAYSENSORSCALED: PHOTOCELL.2, R13.2, R19.1, U7.13 (Y0)
DISPLAYCS: DISP1.OLEDCS; also elsewhere on the board
DISPLAYDC: DISP1.OLEDDC; also elsewhere on the board
GND: 1WIRE.1, C9.2, C10.2, C11.2, C12.2, C13.2, C14.2, C21.2, C22.2, C23.2, C24.2, C25.- (2), C26.2, D4.A, D10.C, DISP1.GND, JP3.2, PHOTOCELL.1, R12.1, R13.1, R21.1, R23.1, R27.1, R29.1, R35.1, U5.1 (GND), U7.6 (!E), U7.7 (VEE), U7.8 (GND), U9.GND, U11.4 (GND), U12.GND; also elsewhere on the board
I2C_SCL: JP3.3, R6.1, SCL.1, U11.6 (SCL); also elsewhere on the board
I2C_SDA: JP3.4, R33.1, SDA.1, U11.5 (SDA); also elsewhere on the board
IRRECEIVER: U9.VOUT, U12.OUT (VOUT); also elsewhere on the board
unnamed: TC-K.2, U5.3 (T+)
unnamed: TC-K.1, U5.2 (T-)
unnamed: U11.1 (X1), Y1.1
unnamed: U11.2 (X2), Y1.4 (2)
unnamed: C25.+ (1), U11.3 (VBACKUP)
unnamed: D10.A, R25.1
ONEWIRE: 1WIRE.2, R24.1; also elsewhere on the board
PERIPHERALRESET: DISP1.RESET, JP3.5, R35.2; also elsewhere on the board
SDCD: DISP1.SDCD; also elsewhere on the board
SDCS: DISP1.SDCS; also elsewhere on the board
SPI_CLK: DISP1.SCK, U5.5 (SCK); also elsewhere on the board
SPI_MISO: DISP1.MISO, U5.7 (SO); also elsewhere on the board
SPI_MOSI: DISP1.MOSI; also elsewhere on the board
THERMOCOUPLECS: R34.1, U5.6 (/CS); also elsewhere on the board
V3.3: 1WIRE.3, C9.1, C21.1, C22.1, C23.1, C24.1, DISP1.VIN, JP3.1, R6.2, R19.2, R24.2, R28.2, R33.2, R34.2, U5.4 (VCC), U7.16 (VCC), U9.VCC, U11.8 (VCC), U12.VCC; also elsewhere on the board
V3P3SCALED: C14.1, R28.1, R29.2, U7.1 (Y4)
V5SW: R11.2; also elsewhere on the board
V5SWSCALED: C10.1, R11.1, R12.2, U7.5 (Y5)
VBATT1: R20.2; also elsewhere on the board
VBATT1SCALED: C11.1, R20.1, R21.2, U7.14 (Y1)
VBATT2: R22.2; also elsewhere on the board
VBATT2SCALED: C12.1, R22.1, R23.2, U7.15 (Y2)
VBATT3: R26.2; also elsewhere on the board
VBATT3SCALED: C13.1, R26.1, R27.2, U7.12 (Y3)

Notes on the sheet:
Sensors
1K light, 10M+ dark
1.45V MAX
4.2V
8.4V
12.6V
1.328V
1.115V
1.216V
1.145V
1.361V
choice

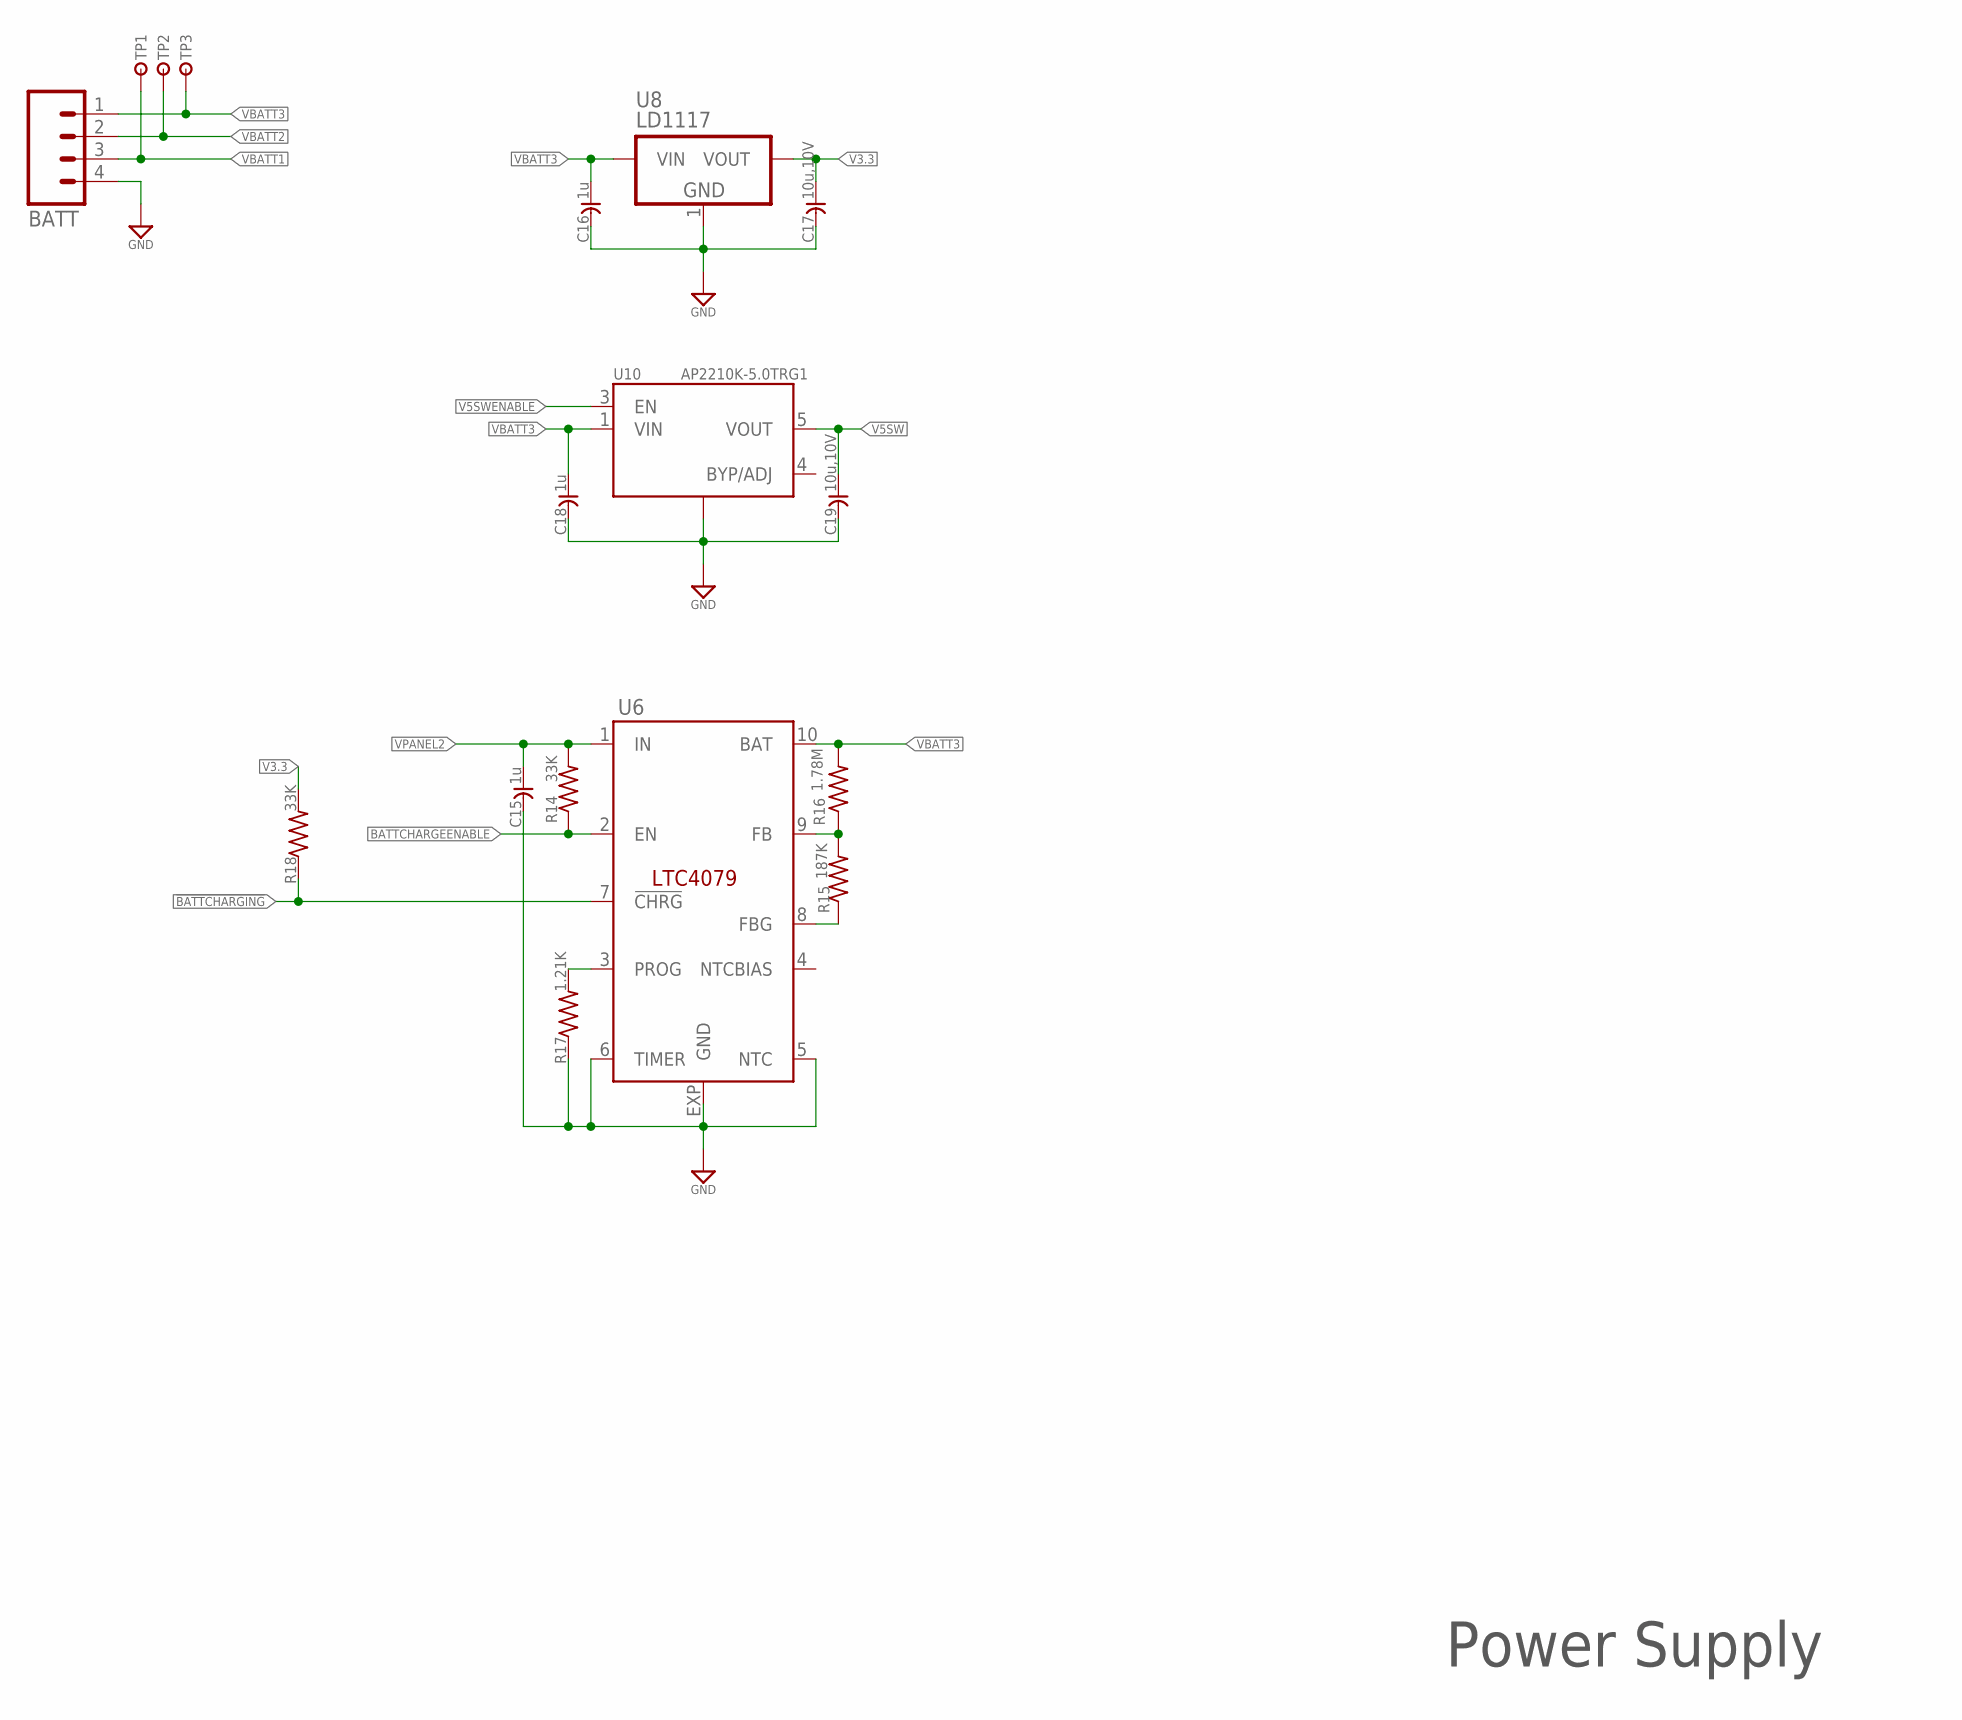
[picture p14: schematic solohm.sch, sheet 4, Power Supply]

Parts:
BATT: M04-B4B-XH-VERT; JST-B4B-XH-VERT
C15, C16, C18: 1u; C0603
C17, C19: 10u,10V; C0805
R14, R18: 33K; R0603
R15: 187K; R0603
R16: 1.78M; R0603
R17: 1.21K; R0603
TP1, TP2, TP3: TESTPOINT0.5; TP0.5R
U6: BATTCHARGER-LTC4079; DFN10-3X3
U8: LD1117; SOT-223
U10: AP2210K-5.0TRG1; SOT23-5

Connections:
!BATTCHARGING: R18.1, U6.7 (!CHRG); also elsewhere on the board
BATTCHARGEENABLE: R14.1, U6.2 (EN); also elsewhere on the board
GND: BATT.4, C15.2, C16.2, C17.2, C18.2, C19.2, R17.1, U6.5 (NTC), U6.6 (TIMER), U6.EXP (GND), U8.1 (GND), U10.2 (GND); also elsewhere on the board
unnamed: R15.2, R16.1, U6.9 (FB)
unnamed: R15.1, U6.8 (FBG)
unnamed: R17.2, U6.3 (PROG)
V3.3: C17.1, R18.2, U8.2 (VOUT); also elsewhere on the board
V5SW: C19.1, U10.5 (VOUT); also elsewhere on the board
V5SWENABLE: U10.3 (EN); also elsewhere on the board
VBATT1: BATT.3, TP1.TP; also elsewhere on the board
VBATT2: BATT.2, TP2.TP; also elsewhere on the board
VBATT3: BATT.1, C16.1, C18.1, R16.2, TP3.TP, U6.10 (BAT), U8.3 (VIN), U10.1 (VIN); also elsewhere on the board
VPANEL2: C15.1, R14.2, U6.1 (IN); also elsewhere on the board

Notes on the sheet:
Power Supply

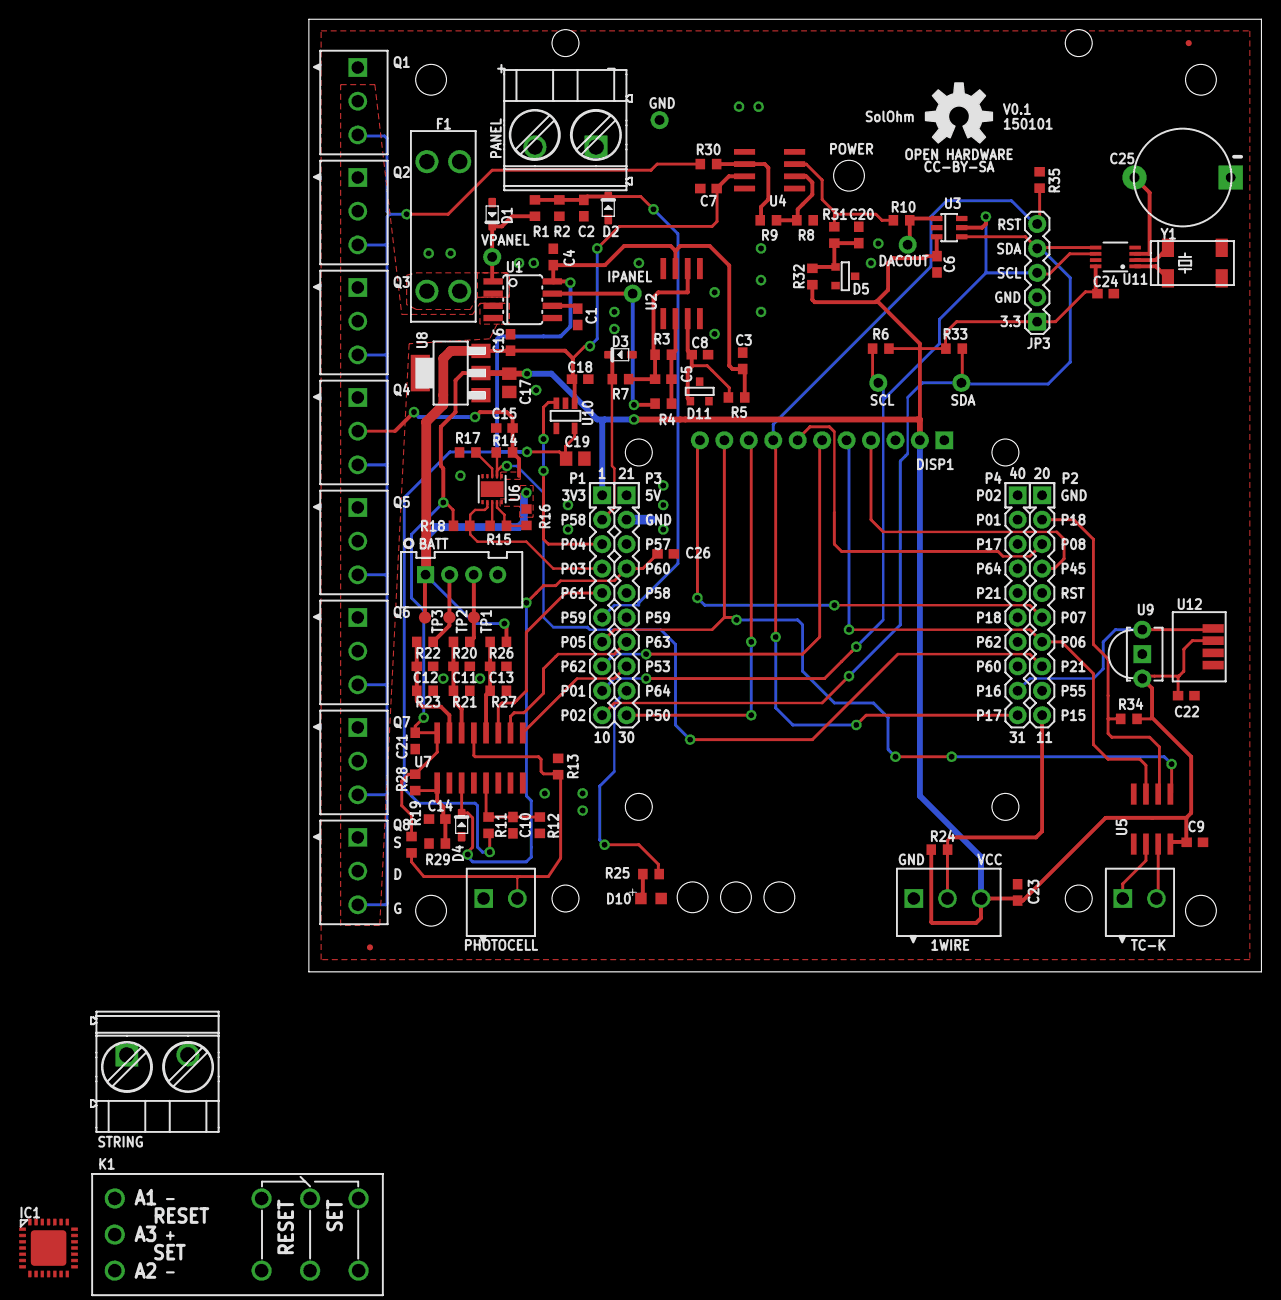
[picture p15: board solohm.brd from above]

Board: 2 copper layers, 99.0 x 99.0 mm, 113 parts (0 on the bottom side), 59 nets.

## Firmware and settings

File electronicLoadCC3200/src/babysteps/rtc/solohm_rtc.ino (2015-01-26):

#include <Wire.h>

byte	rtc_bcd[7]; 

// from https://github.com/sridharrajagopal/DSRTCLib
// indices within the rtc_bcd[] buffer

#define DSRTCLib_TR     0x10
#define DSRTCLib_SEC	0
#define DSRTCLib_MIN	1
#define DSRTCLib_HR	2
#define DSRTCLib_DOW	3
#define DSRTCLib_DATE     4
#define DSRTCLib_MTH	5
#define DSRTCLib_YR	6

#define DSRTCLib_BASE_YR		2000

#define DSRTCLib_CTRL_ID		B1101000

// Define register bit masks

#define DSRTCLib_CLOCKHALT	B10000000

#define DSRTCLib_LO_BCD		B00001111
#define DSRTCLib_HI_BCD		B11110000

#define DSRTCLib_HI_SEC		B01110000
#define DSRTCLib_HI_MIN		B01110000
#define DSRTCLib_HI_HR		B00110000
#define DSRTCLib_LO_DOW		B00000111
#define DSRTCLib_HI_DATE		B00110000
#define DSRTCLib_HI_MTH		B00110000
#define DSRTCLib_HI_YR		B11110000

#define DSRTCLib_ARLM1		0x07
#define DSRTCLib_ARLM1_LO_SEC	B00001111
#define DSRTCLib_ARLM1_HI_SEC	B01110000
#define DSRTCLib_ARLM1_LO_MIN	B01110000
#define DSRTCLib_ARLM1_HI_MIN	B00001111

#define DSRTCLib_SP			0x0E
#define	DSRTCLib_SP_EOSC		B10000000
#define	DSRTCLib_SP_RS2		B00010000
#define	DSRTCLib_SP_RS1		B00001000
#define	DSRTCLib_SP_INTCN		B00000100
#define	DSRTCLib_SP_A2IE		B00000010
#define	DSRTCLib_SP_A1IE		B00000001

#define DSRTCLib_STATUS		0x0F
#define DSRTCLib_STATUS_OSF	B10000000
#define DSRTCLib_STATUS_A2F	B00000010
#define DSRTCLib_STATUS_A1F	B00000001

// Cumulative number of days elapsed at the start of each month, assuming a normal (non-leap) year.
const unsigned int monthdays[] = {
  0, 31, 59, 90, 120, 151, 181, 212, 243, 273, 304, 334};


void writeTime(void)
{
  Wire.beginTransmission(DSRTCLib_CTRL_ID);
  Wire.write((uint8_t)0x00); // reset register pointer
  for(int i=0; i<7; i++)
  {
    Wire.write(rtc_bcd[i]);
  }
  Wire.endTransmission();

  // clear the Oscillator Stop Flag
  setRegister(DSRTCLib_STATUS, getRegister(DSRTCLib_STATUS) & !DSRTCLib_STATUS_OSF);
}


void setRegister(unsigned char registerNumber, unsigned char value)
{
  Wire.beginTransmission(DSRTCLib_CTRL_ID);
  Wire.write(registerNumber); // set register pointer
  Wire.write(value);
  Wire.endTransmission();
}

unsigned char getRegister(unsigned char registerNumber)
{
  Wire.beginTransmission(DSRTCLib_CTRL_ID);
  Wire.write(registerNumber);
  Wire.endTransmission();
  Wire.requestFrom(DSRTCLib_CTRL_ID, 1);
  return Wire.read();
}
byte bin2bcd(byte v)
{
  return ((v / 10)<<4) + (v % 10);
}

byte bcd2bin(byte v)
{
  return (v&0x0F) + ((v>>4)*10);
}



void epoch_seconds_to_date(unsigned long seconds_left)
{
  // This routine taken from Dallas/Maxim application note 517
  // http://www.maxim-ic.com/app-notes/index.mvp/id/517
  // Arn't the fastest thing, but it produces correct results.

  // NOTE: The earliest date that can be represented by the DS1337 & DS1339 is 1/1/2000 (946684800 in Unix epoch seconds).
  // Passing an earlier Unix time stamp will fail quietly here (produce a date of 0/0/00), 
  // which will probably make your application angry.

  // ALSO NOTE: This has been optimized some to minimize redundant variables, with the side-effect
  // of making it much harder to understand. Please refer to the original appnote above
  // if you are trying to learn from it :-)


  //unsigned long hour;
  //unsigned long day;
  //unsigned long minute;
  //unsigned long second;
  unsigned long month;
  //unsigned long year;

  unsigned long seconds_left_2;
  //unsigned long whole_minutes;
  //unsigned long whole_hours;
  //unsigned long whole_days;
  //unsigned long whole_days_since_1968;
  unsigned long leap_year_periods;
  unsigned long days_since_current_lyear;
  //unsigned long whole_years;
  unsigned long days_since_first_of_year;
  unsigned long days_to_month;
  //unsigned long day_of_week;

  if(seconds_left >= 946684800)
  {
    seconds_left -= 946684800; // correct for difference between DS1337/DS1339 and UNIX epochs.

    seconds_left_2 = seconds_left / 60; // seconds_left_2 = "whole_minutes"
    rtc_bcd[DSRTCLib_SEC] = bin2bcd(seconds_left - (60 * seconds_left_2));                 // leftover seconds

    seconds_left = seconds_left_2 / 60; // seconds_left = "whole_hours"
    rtc_bcd[DSRTCLib_MIN] = bin2bcd(seconds_left_2 - (60 * seconds_left));            // leftover minutes

    seconds_left_2 = seconds_left / 24; //seconds_left_2 = "whole_days"
    rtc_bcd[DSRTCLib_HR] = bin2bcd(seconds_left - (24 * seconds_left_2));         // leftover hours

    //whole_days_since_1968 = whole_days;// + 365 + 366;	// seconds_left_2 = "whole_days" = "whole_days_since_1968"
    leap_year_periods = seconds_left_2 / ((4 * 365) + 1);

    days_since_current_lyear = seconds_left_2 % ((4 * 365) + 1);

    // if days are after a current leap year then add a leap year period
    if ((days_since_current_lyear >= (31 + 29))) {
      leap_year_periods++;
    }
    seconds_left = (seconds_left_2 - leap_year_periods) / 365; // seconds_left = "whole_years"
    days_since_first_of_year = seconds_left_2 - (seconds_left * 365) - leap_year_periods;

    if ((days_since_current_lyear <= 365) && (days_since_current_lyear >= 60)) {
      days_since_first_of_year++;
    }
    //year = seconds_left; // + 68;


    // seconds_left = "year"
    //seconds_left_2 = "month"
    // walk across monthdays[] to find what month it is based on how many days have passed
    //   within the current year
    month = 13;
    days_to_month = 366;
    while (days_since_first_of_year < days_to_month) {
      month--;
      days_to_month = monthdays[month-1];
      if ((month > 2) && ((seconds_left % 4) == 0)) {
        days_to_month++;
      }
    }

    rtc_bcd[DSRTCLib_DATE] = bin2bcd( days_since_first_of_year - days_to_month + 1);

    rtc_bcd[DSRTCLib_DOW] = bin2bcd((seconds_left_2  + 4) % 7);


    //rtc_bcd[DSRTCLib_SEC] = bin2bcd(second);
    //rtc_bcd[DSRTCLib_MIN] = bin2bcd(minute);
    //rtc_bcd[DSRTCLib_HR] = bin2bcd(hour);
    //rtc_bcd[DSRTCLib_DATE] = bin2bcd(day);
    //rtc_bcd[DSRTCLib_DOW] = bin2bcd(day_of_week);
    rtc_bcd[DSRTCLib_MTH] = bin2bcd(month);
    rtc_bcd[DSRTCLib_YR] = bin2bcd(seconds_left);
  }
  else
  {
    // else: "invalid" (< year 2000) epoch format.
    // 'Best' way to handle this is to zero out the returned date. 

    rtc_bcd[DSRTCLib_SEC] = 0; //0x00 binary = 0x00 BCD
    rtc_bcd[DSRTCLib_MIN] = 0;
    rtc_bcd[DSRTCLib_HR] = 0;
    rtc_bcd[DSRTCLib_DATE] = 0;
    rtc_bcd[DSRTCLib_DOW] = 0;
    rtc_bcd[DSRTCLib_MTH] = 0;
    rtc_bcd[DSRTCLib_YR] = 0;
  }

}

unsigned char time_is_set()
{
  // Return TRUE if Oscillator Stop Flag is clear (osc. not stopped since last time setting), FALSE otherwise
  byte asdf = ((getRegister(DSRTCLib_STATUS) & DSRTCLib_STATUS_OSF) == 0);
  return asdf;
}


void setup()
{
  Wire.begin();
  Serial.begin(115200);
  Serial.println("begin solohm_rtc");

  setRegister(DSRTCLib_SP, getRegister(DSRTCLib_SP) & !DSRTCLib_SP_EOSC); //start RTC
  setRegister(DSRTCLib_TR,0xA6); // no diode, 2k resistor;

//     epoch_seconds_to_date(1421908160L);
//    writeTime();


  if(!time_is_set()) // set a time, if none set already...
  {
    Serial.print("Clock not set. ");
    epoch_seconds_to_date(1421906711L);
    writeTime();
  }

}

void loop()
{ 

  Wire.beginTransmission(DSRTCLib_CTRL_ID);
  Wire.write((uint8_t)0x00);
  Wire.endTransmission();

  // request the 7 bytes of data    (secs, min, hr, dow, date. mth, yr)
  Wire.requestFrom(DSRTCLib_CTRL_ID, 7);

  for(int i=0; i<7; i++)
  {
    if (Wire.available()) {
      rtc_bcd[i] = Wire.read();
    }
  }

  for(int i=6; i>=0; i--)
  {
    Serial.print(bcd2bin(rtc_bcd[i]),DEC);
    Serial.print(" ");
  }
  Serial.println();

  delay(1000);
}

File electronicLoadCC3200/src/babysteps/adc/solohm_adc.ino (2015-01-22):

#include "solohm.h"

#define VBATT1SCALE  4.136/3057.0
#define VBATT2SCALE  8.279/3351.0
#define VBATT3SCALE 12.413/3130.0
#define V3P3SCALE    3.32/3836.0
#define V5SCALE      5.00/3712.0
#define VPANELSCALE 25.44/2081.0
#define IPANELM     -0.0025316
#define IPANELB      9.6075949


int amuxRead(uint8_t channel) {
  switch (channel) {
  case DAYSENSORSCALED:      
    digitalWrite(AMUXS0,0);
    digitalWrite(AMUXS1,0);
    digitalWrite(AMUXS2,0);
    break;
  case VBATT1SCALED:      
    digitalWrite(AMUXS0,1);
    digitalWrite(AMUXS1,0);
    digitalWrite(AMUXS2,0);
    break;
  case VBATT2SCALED:      
    digitalWrite(AMUXS0,0);
    digitalWrite(AMUXS1,1);
    digitalWrite(AMUXS2,0);
    break;
  case VBATT3SCALED:      
    digitalWrite(AMUXS0,1);
    digitalWrite(AMUXS1,1);
    digitalWrite(AMUXS2,0);
    break;
  case V3P3SCALED:      
    digitalWrite(AMUXS0,0);
    digitalWrite(AMUXS1,0);
    digitalWrite(AMUXS2,1);
    break;
  case V5SWSCALED:      
    digitalWrite(AMUXS0,1);
    digitalWrite(AMUXS1,0);
    digitalWrite(AMUXS2,1);
    break;
  }
  delay(100);
  return analogRead(AMUXOUT);
}

void setup() {
  Serial.begin(115200);
  pinMode(VPANELSCALED,INPUT);
  pinMode(IPANELSCALED,INPUT);
  pinMode(AMUXOUT,INPUT);

  pinMode(AMUXS0,OUTPUT);
  pinMode(AMUXS1,OUTPUT);
  pinMode(AMUXS2,OUTPUT);
  pinMode(V5SWENABLE,OUTPUT);
  digitalWrite(V5SWENABLE,1);

  Serial.println("solohm_adc begin");
}

void loop() {
  int adc;
  float value;

  adc = analogRead(VPANELSCALED);
  Serial.print("VPANELSCALED    ");
  value = adc * VPANELSCALE;
  Serial.println(value,2);

  adc = analogRead(IPANELSCALED);
  value = IPANELM * adc + IPANELB;
  Serial.print("IPANELSCALED    ");
  Serial.println(value,2);


  adc = amuxRead(DAYSENSORSCALED);
  Serial.print("DAYSENSORSCALED ");
  Serial.println(adc,DEC);


  adc = amuxRead(VBATT1SCALED);
  Serial.print("VBATT1SCALED    ");
  value = adc * VBATT1SCALE;
  Serial.println(value,2);

  adc = amuxRead(VBATT2SCALED);
  Serial.print("VBATT2SCALED    ");
  value = adc * VBATT2SCALE;
  Serial.println(value,2);

  adc = amuxRead(VBATT3SCALED);
  Serial.print("VBATT3SCALED    ");
  value = adc * VBATT3SCALE;
  Serial.println(value,2);

  adc = amuxRead(V3P3SCALED);
  Serial.print("V3P3SCALED      ");
  value = adc * V3P3SCALE;
  Serial.println(value,2);

  adc = amuxRead(V5SWSCALED);
  Serial.print("V5SWSCALED      ");
  value = adc * V5SCALE;
  Serial.println(value,2);

  Serial.println();
  delay(900);
}

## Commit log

2015-01-03 initial add
    [solohm.brd, solohm.sch]
2015-01-05 here's the v0.1 hardware version, sent this to board house for fab
    [solohm.brd, solohm.sch]
2015-01-09 changed top silk char width
    [solohm.brd, solohm.sch]
2015-01-11 added disconnect for operation in string
    [solohm.brd, solohm.sch]
2015-01-12 added dual-coil latching relay and 23017 I/O port for future battery charger control
    [solohm.brd, solohm.sch]
2015-01-13 fixed a bunch of top silk errors here and there
    [solohm.brd, solohm.sch]
2015-01-13 just tweaking things from v0.1 board problems
    [solohm.brd, solohm.sch]
2015-01-20 initial add for src little tweaks to the board added lines to board design notes file
    [solohm.brd, solohm.sch]
2015-01-22 fixed amux ground islands ino has functional vbatt sensing
    [solohm.brd]
2015-01-26 added more notes created testing data from MOSFET/heatsink temperature testing bs/solohm_dac now is keyboard driven bs/rtc functional
2015-01-26 solohm app add adc, dac and udp to SolOhm class, now broadcasts on 8380
2015-01-31 added mode, rload now reporting individual battery voltages and 'vbatt'(all in series)
2015-09-21 dir reorg
    [150201 - 190W panel.csv, 150201 - 60W panel.csv, solohm.brd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]

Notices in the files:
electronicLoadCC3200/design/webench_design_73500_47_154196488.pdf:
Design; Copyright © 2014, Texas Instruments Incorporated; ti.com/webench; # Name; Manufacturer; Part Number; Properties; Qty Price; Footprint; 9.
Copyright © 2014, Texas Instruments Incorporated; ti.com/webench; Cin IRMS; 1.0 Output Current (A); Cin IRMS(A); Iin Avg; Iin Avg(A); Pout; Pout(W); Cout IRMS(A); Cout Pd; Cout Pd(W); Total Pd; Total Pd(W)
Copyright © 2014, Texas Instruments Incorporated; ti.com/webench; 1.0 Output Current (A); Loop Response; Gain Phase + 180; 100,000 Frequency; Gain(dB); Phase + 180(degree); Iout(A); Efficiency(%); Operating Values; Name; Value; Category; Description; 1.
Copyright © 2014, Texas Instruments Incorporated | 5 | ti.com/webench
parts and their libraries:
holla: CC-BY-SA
